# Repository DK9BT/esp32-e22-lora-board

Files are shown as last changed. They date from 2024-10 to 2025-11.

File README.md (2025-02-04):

# ESP32-E22-LoRa-board
Carrier Board for LoRa Tranceiver like E22-400M33S and ESP32 MCU

### Main Parts List:

EBYTE E22-400M33S (2W/33dBm) https://www.amazon.de/dp/B0BMP99S3D

if needed: E22->N Pigtail: https://www.amazon.de/dp/B0C8J131PD

ESP32 Board Dev Kit C V4 https://www.amazon.de/dp/B08BTS62L7/ / https://www.amazon.de/dp/B07Z83MF5W/

Adapter-Kabel zum flashen im eingebauten Zustand https://www.amazon.de/dp/B096843RY3/

BME/BMP280 3,3V https://www.amazon.de/dp/B07FS95JXT/

OLED-Display (VCC-GND-SCL-SDA): https://www.amazon.de/dp/B0C9LJ898Z/

GPS https://www.amazon.de/dp/B0D3DJ58R8/

Reichelt: https://www.reichelt.de/my/2192127

### Versions Info
**V 2.1.2  PCB** für Querformat im Gehäuse für Aussenmontage - alle Anschlüsse auf der Unterseite des Gehäuses  
oder PCB vertikale Einbau

___

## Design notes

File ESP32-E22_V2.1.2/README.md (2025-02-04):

# ESP32-E22-LoRa-board V2.1.2 - FINAL
• Carrier Board for Lora Tranceiver like E22-400M33S and ESP32 MCU  

siehe Bestückungshinweise

___
***OE3WAS - Wolfgang - 4.2.2025***

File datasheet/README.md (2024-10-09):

# Quellenverzeichnis / Links
Symbols, Footprints, 3D-Modelle

https://kicad.github.io/packages3d/  
https://support.snapmagic.com/en/articles/3758108-how-to-import-a-3d-model-in-kicad

### SMA
https://kicad.github.io/footprints/Connector_Coaxial  
https://www.snapeda.com/parts/221789-1/TE%20Connectivity/view-part/  
https://www.snapeda.com/parts/CON-SMA-EDGE-S/RF%20Solutions/view-part/  

### E22 
https://www.snapeda.com/parts/E22-400M30S/EBYTE/view-part/

### ESP32
https://grabcad.com/library/esp32-devkitc-v4-1

...

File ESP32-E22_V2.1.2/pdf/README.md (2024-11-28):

### PDF files for easier viewing

**SCH** = schematic  
**PCB** = board  
~~**_3D** = 3D files for 360° viewing~~  
**BOM** = Stückliste

~~for **3D-PDF**s you can use the **Adobe Acrobar Reader**  
or **PDF Xchange Editor** https://www.pdf-xchange.com/product/pdf-xchange-editor~~

## Bestückungsplan
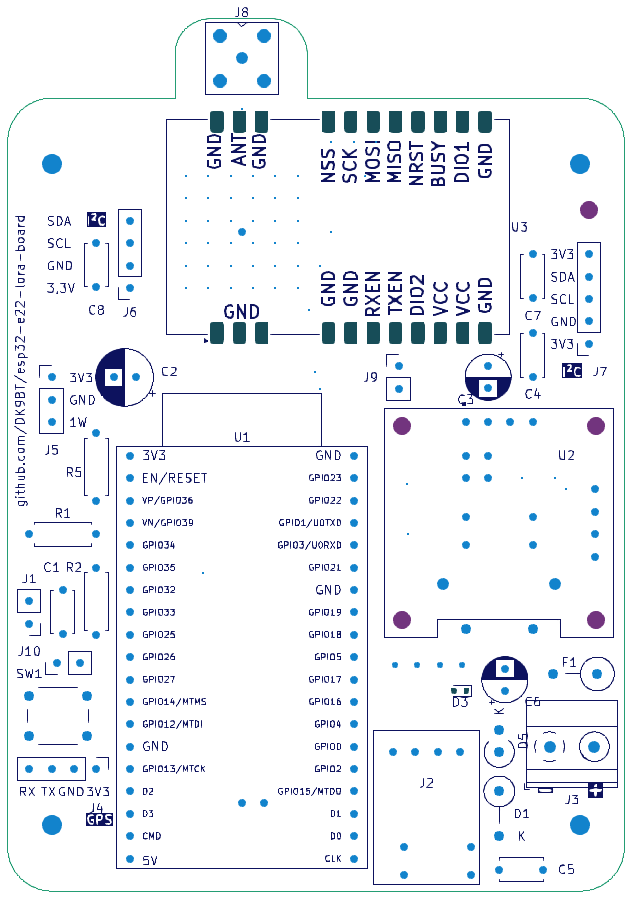
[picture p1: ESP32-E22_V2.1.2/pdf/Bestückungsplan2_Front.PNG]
  
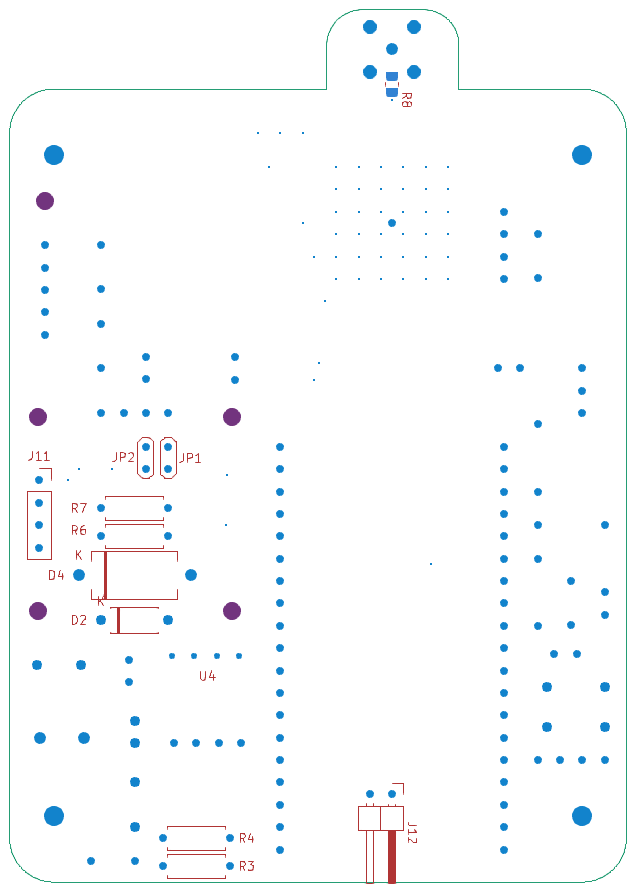
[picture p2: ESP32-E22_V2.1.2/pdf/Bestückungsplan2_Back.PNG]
  

## Querformat-Einbau für Outdoor
= alle Ausgänge an der Unterseite (OLED um 90° gedreht bestücken möglich)  
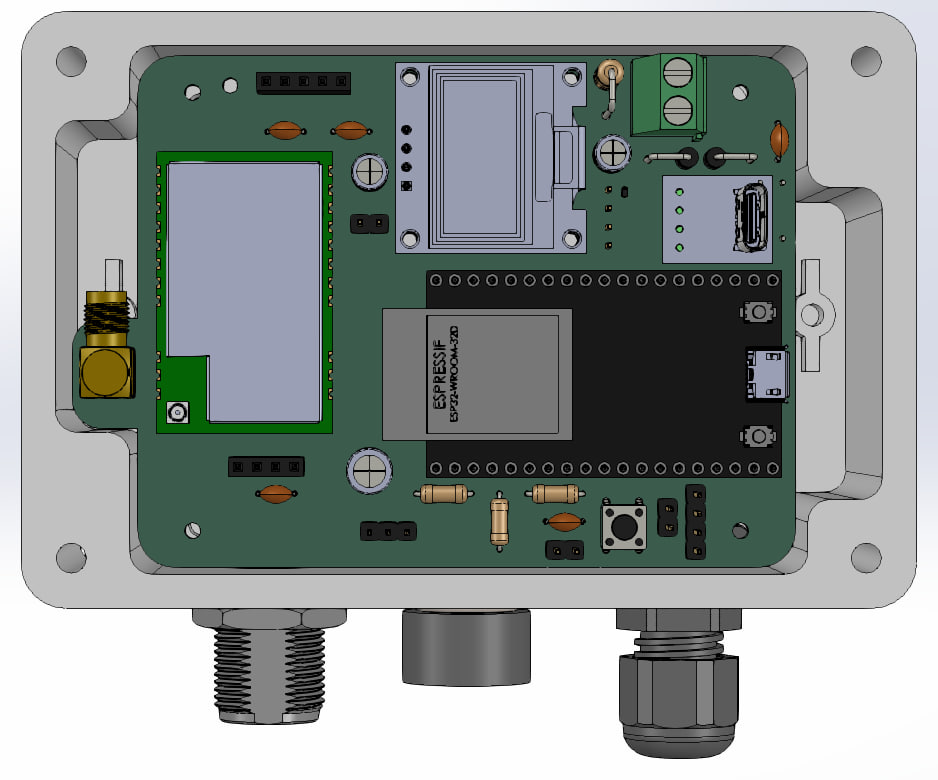
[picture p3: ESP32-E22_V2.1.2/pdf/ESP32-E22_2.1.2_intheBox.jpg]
InTheBox1
  
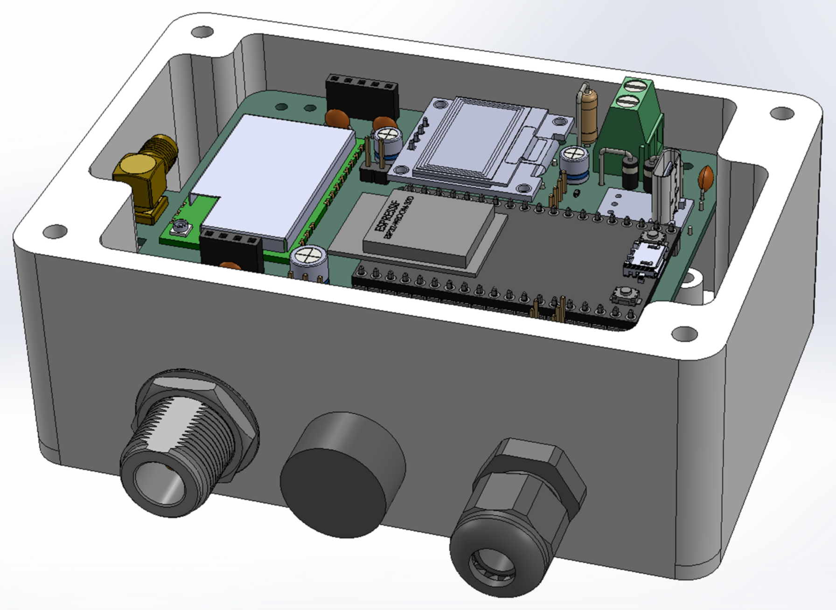
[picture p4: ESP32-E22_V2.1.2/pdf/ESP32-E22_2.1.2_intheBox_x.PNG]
InTheBox2
  
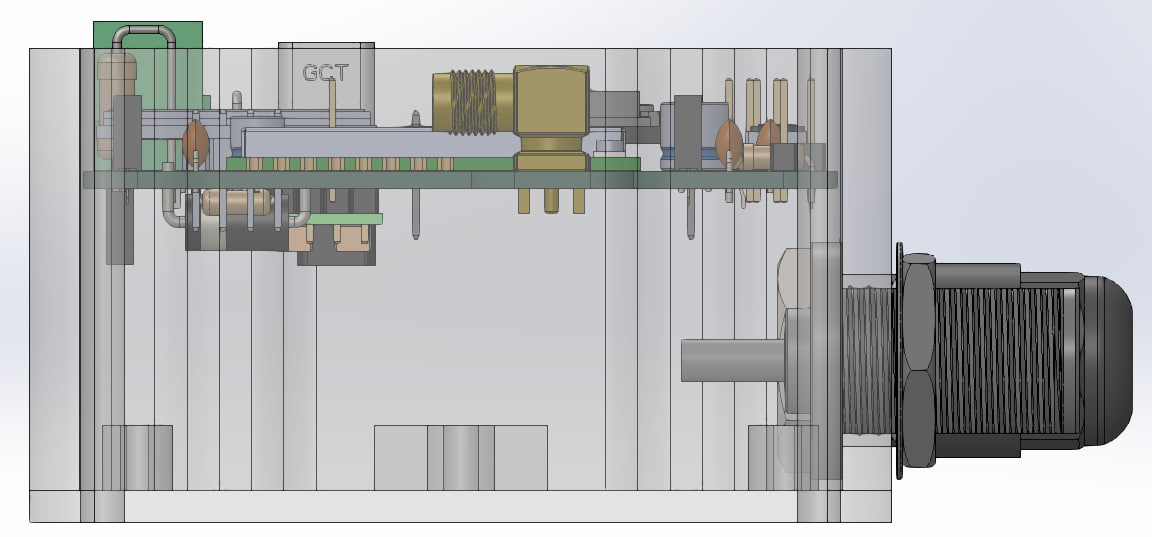
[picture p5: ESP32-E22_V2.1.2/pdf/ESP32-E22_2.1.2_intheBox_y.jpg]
InTheBox3


## Hochformat-Einbau
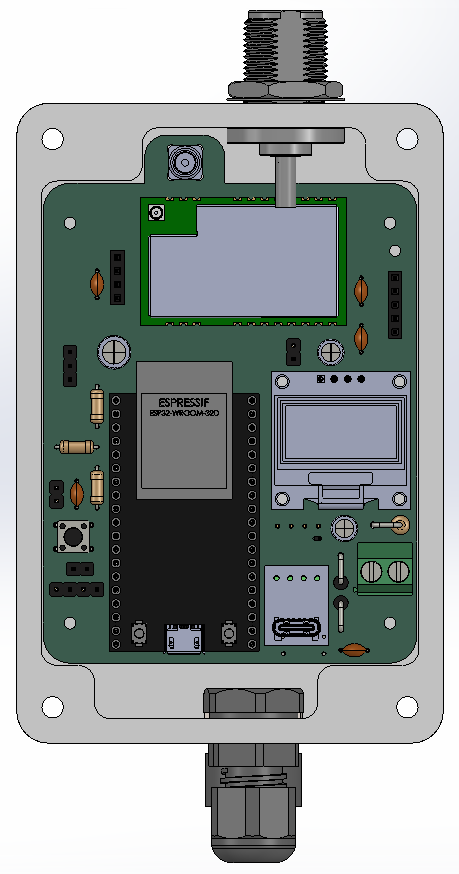
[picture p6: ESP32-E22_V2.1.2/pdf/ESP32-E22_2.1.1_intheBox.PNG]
InTheBox1
  
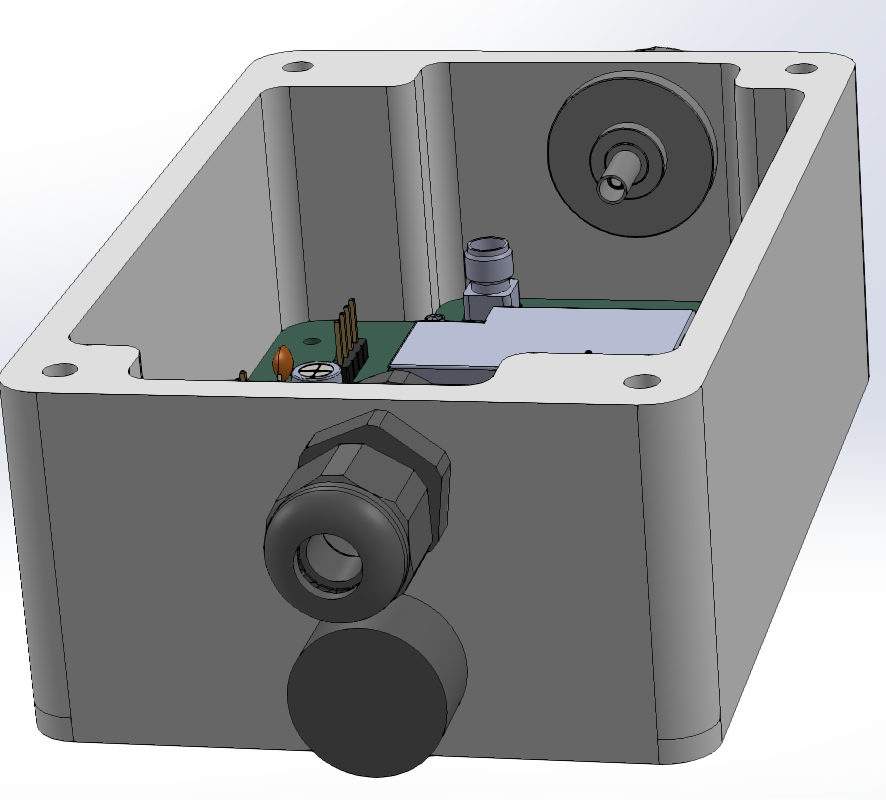
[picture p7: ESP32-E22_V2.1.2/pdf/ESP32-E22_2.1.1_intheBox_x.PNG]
InTheBox2


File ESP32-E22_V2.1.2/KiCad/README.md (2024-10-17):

### full KiCad Project

with KiCad V 8.0.5

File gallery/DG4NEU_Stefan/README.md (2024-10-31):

### DG4NEU - Stefan - Prototyp V2.1.0 Impressionen

alle Fotos mit freundlicher Genehmigung von (c) **DG4NEU Stefan**

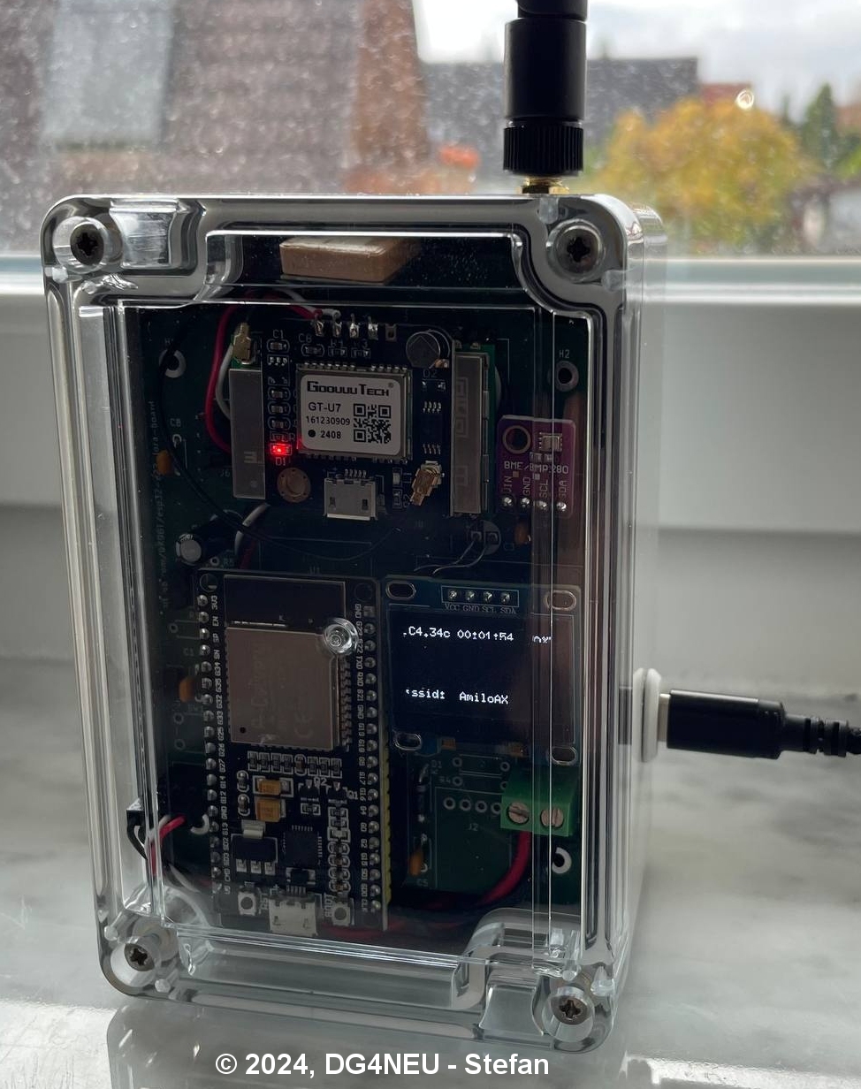
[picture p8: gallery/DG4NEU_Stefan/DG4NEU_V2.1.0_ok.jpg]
Fertiggerät


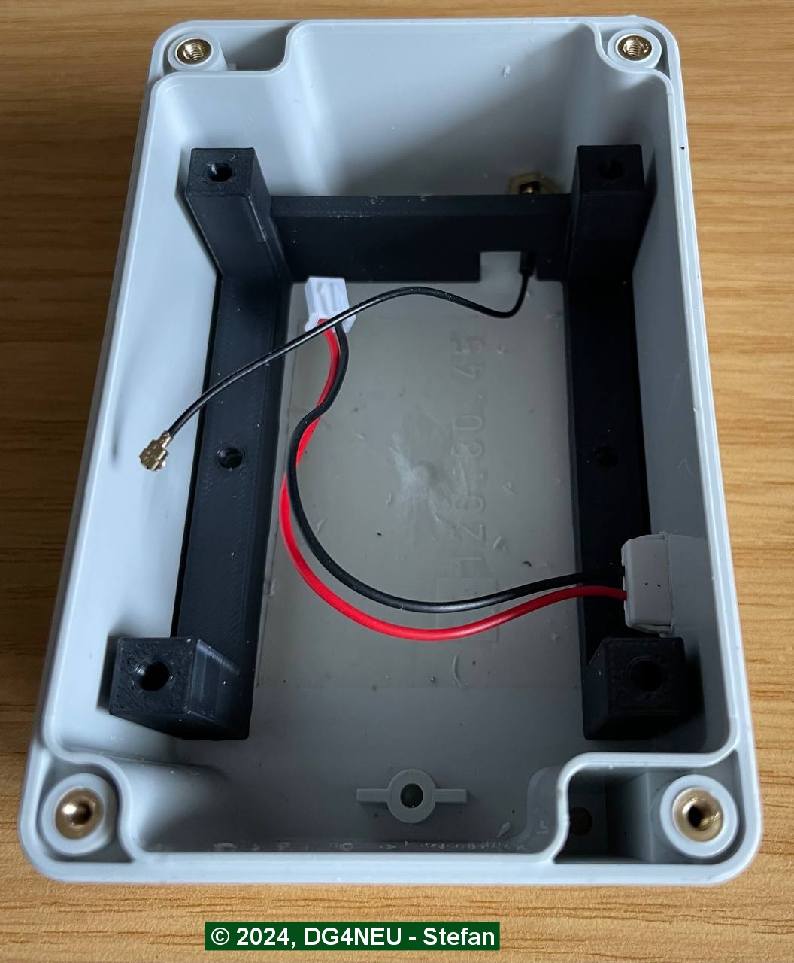
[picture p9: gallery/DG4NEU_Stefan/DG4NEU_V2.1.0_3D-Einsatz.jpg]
3D-Einsatz


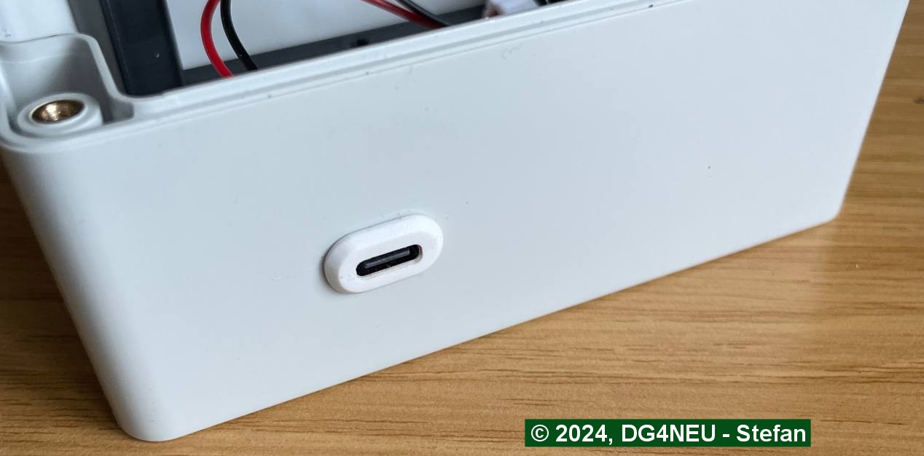
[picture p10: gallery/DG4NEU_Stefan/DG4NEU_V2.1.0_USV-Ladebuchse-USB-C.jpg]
USV-Ladebuchse-USB-C


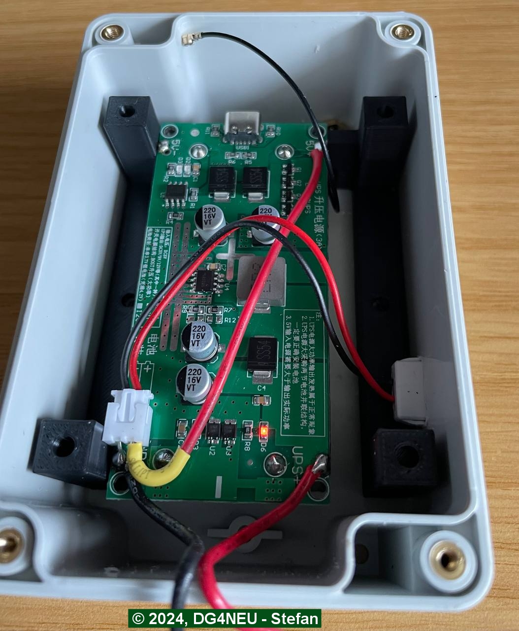
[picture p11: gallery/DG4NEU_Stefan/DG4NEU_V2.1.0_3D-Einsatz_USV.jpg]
3D-Einsatz+USV


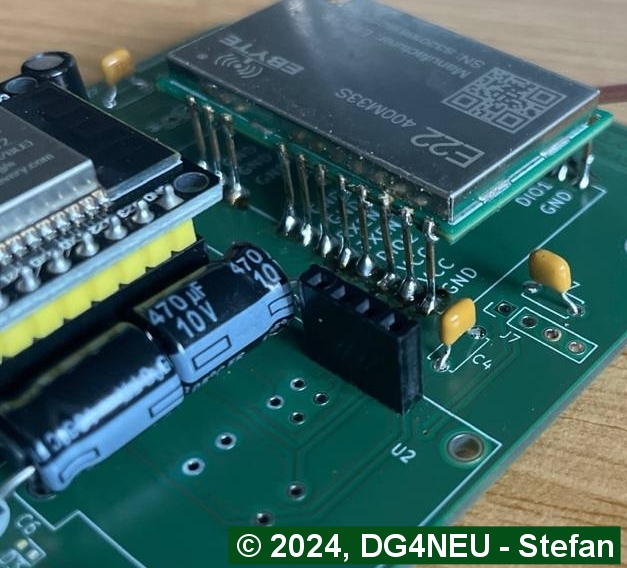
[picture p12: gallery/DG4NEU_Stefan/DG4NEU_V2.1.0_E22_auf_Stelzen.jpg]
E22_auf_Stelzen


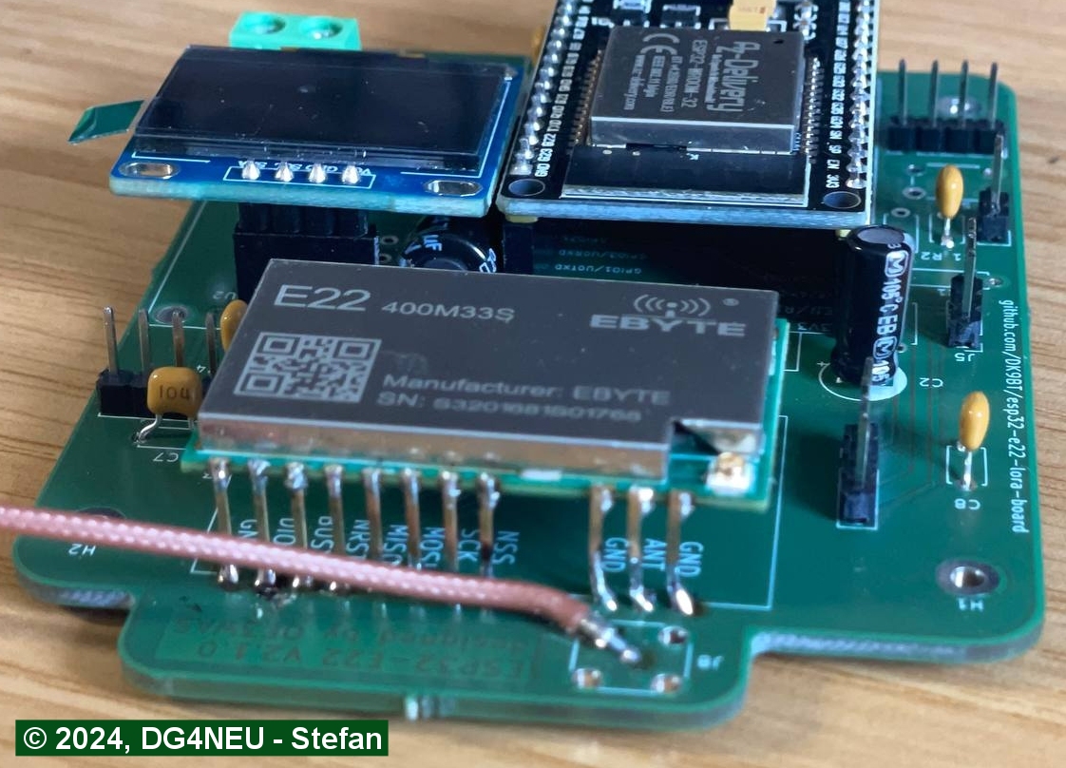
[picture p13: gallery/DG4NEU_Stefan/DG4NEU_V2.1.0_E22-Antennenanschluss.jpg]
E22+Antennenanschluss


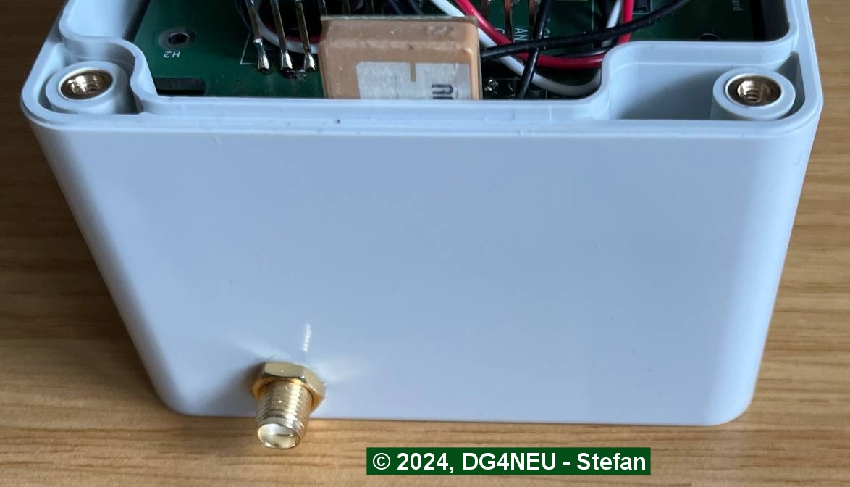
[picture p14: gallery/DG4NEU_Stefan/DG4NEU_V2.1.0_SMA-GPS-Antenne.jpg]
SMA+GPS-Antenne


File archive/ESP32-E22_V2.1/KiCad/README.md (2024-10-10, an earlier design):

### full KiCad Project

with KiCad V 8.0.5  

Beta-Version  
SCH V 2.0.11  
PCB V 2.0.6  

**Offene Fragen / Probleme, die in der nächsten Version behoben werden:**

• GND Flood

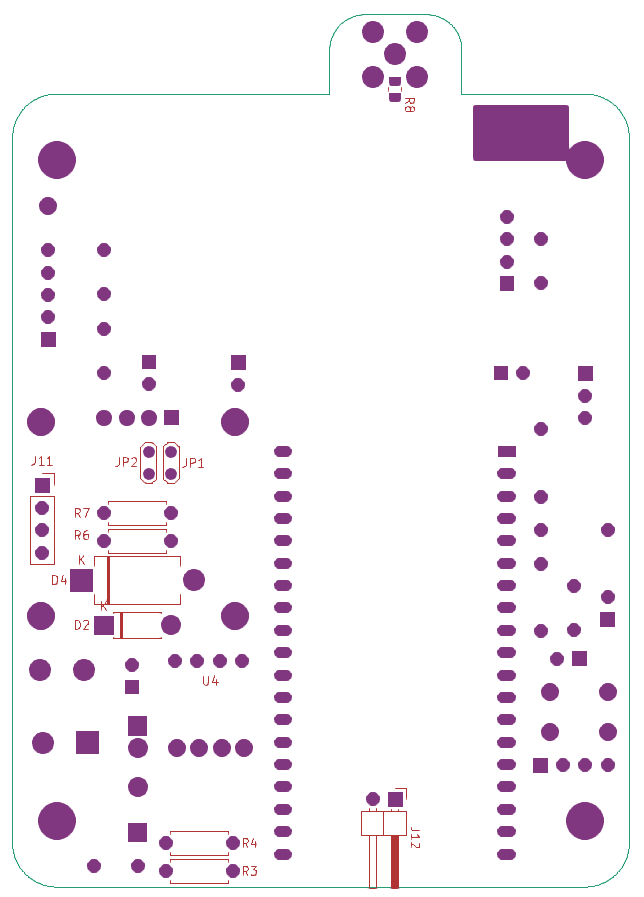
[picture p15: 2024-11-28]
ESP32-E22_V2.1.2/pdf/Bestückungsplan_Back.PNG

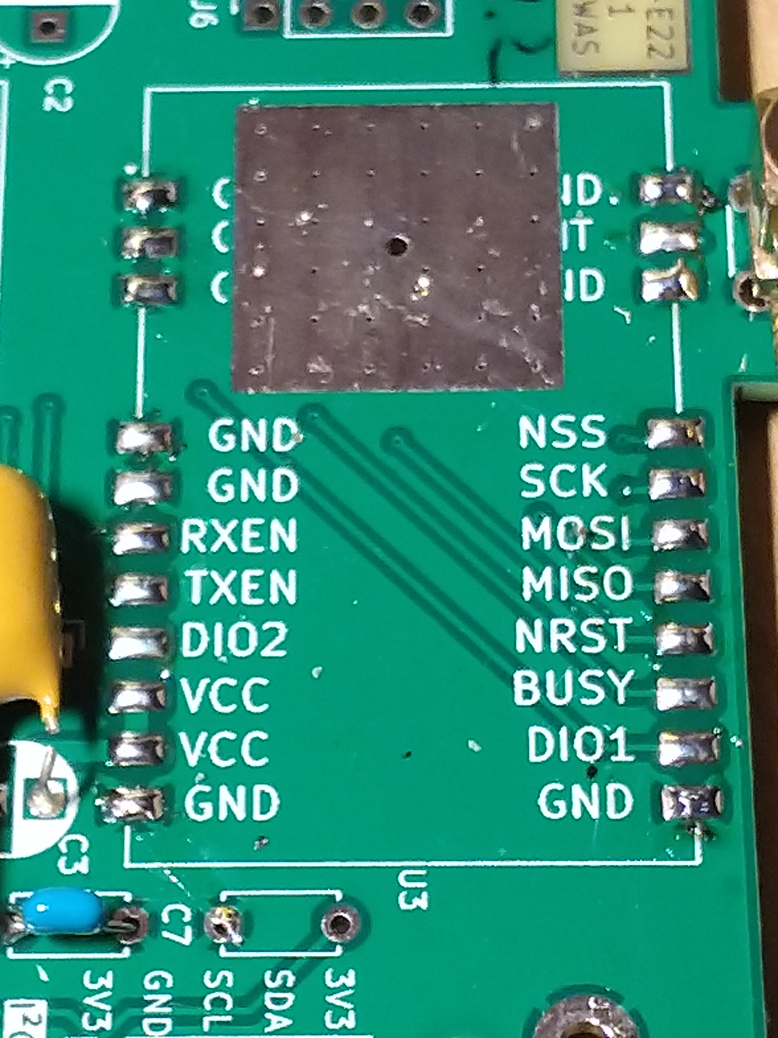
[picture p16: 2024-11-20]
ESP32-E22_V2.1.2/picass/1-1_E22_SMD.jpg

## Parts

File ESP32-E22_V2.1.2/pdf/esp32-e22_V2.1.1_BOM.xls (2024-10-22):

ESP32-E22 V 2.1.1
lfd.Nr. | Qty | Type | Value | Reference | Info
1 | 1 | ESP32-Modul | ESP32-DevKitC | U1 | …
2 | 1 | LoRa-Funkmodul | E22-400M33S | U3 | …M30S = 30dBm = 1W bzw. …M33S = 33dBm = 2W
3 | 1 | OLED-Display | DM-OLED096-636 | U2 | !!! auf das Pinning achten: VCC GND SCL SDA
4 | 1 | USB-C Adapter Board | vertical | J2 | Aliexpress https://de.aliexpress.com/item/1005007821332638.html
6 | 1 | SMA-Buchse | SMA | J8 | SMA_Amphenol_132134-14_Vertical
7 | 5 | Keramik-Kondensator | 100 nF | C1,C4,C5,C7,C8 | Capacitor_THT:C_Disc_D4.7mm_W2.5mm_P5.00mm
8 | 1 | Elektrolyt-Kondensator | 10 µF / 10V | C2 | Capacitor_THT:CP_Radial_D6.3mm_P2.50mm
9 | 2 | Elektrolyt-Kondensator | 470 µF / 10V | C3,C6 | Capacitor_THT:CP_Radial_D5.0mm_P2.50mm
10 | 2 | Schottky-Diode | 1N5817 | D1,D2 | Diode_THT:D_DO-41_SOD81_P7.62mm_Horizontal
11 | 1 | ESD-Schutz-Diode | LESD5D5.0CT1G | D3 | Diode_SMD:D_SOD-523
12 |  | ESD-Schutz-Diode | 1N5908 | D3 | alternativ auf Rückseite auflöten
13 | 1 | Sicherung | 5A | F1 | https://www.conrad.at/de/p/littelfuse-0874002-mxep-0874002-mxep-sicherung-inhalt-1-st-bulk-2943788.html
14 | 2 | Widerstand | 5k1 | R1,R2 | Resistor_THT:R_Axial_DIN0207_L6.3mm_D2.5mm_P7.62mm_Horizontal
15 | 2 | Widerstand | *) | R3,R4 | *) Werte für Spannungsteiler je nach Bedarf
16 | 1 | Widerstand | 4k7 | R5 | Resistor_THT:R_Axial_DIN0207_L6.3mm_D2.5mm_P7.62mm_Horizontal
17 | 2 | Widerstand | 10k | R6,R7 | Resistor_THT:R_Axial_DIN0207_L6.3mm_D2.5mm_P7.62mm_Horizontal
18 | 1 | Jumper | 0R | R8 | Resistor_SMD:R_0805_2012Metric
19 | 1 | Taster |  | SW1 | Button_Switch_THT:SW_PUSH_6mm
20 | 1 | Schraubklemme | 2-pol | J1 | z.B. Phoenix_MKDS-1,5-2-5.08_1x02_P5.08mm_Horizontal
21 | 2 | St-/Bu-Leiste | Conn_01x02._Socket | J3,J9 | PinHeader_1x02_P2.54mm_Vertical
22 | 1 | St-/Bu-Leiste | Conn_01x03_Socket | J5 | PinHeader_1x03_P2.54mm_Vertical
23 | 3 | St-/Bu-Leiste | Conn_01x04_Socket | J4,J6,J7 | PinHeader_1x04_P2.54mm_Vertical
24 | 1 | PCB | ESP32-E22 V2.1.0
25 | 1 | Gehäuse | 120x80x60 | 6U07120806017 | Reichelt #340515 od. transparenter Deckel #340524 (6U07120806437)
26 | 4 | Schraube | M2x6 (M2x8) | PCB | Befestigung im Gehäuse, siehe "Modellbauschrauben"
27 | 2 | Schraube | M2x15 (?) | OLED | Befestigung auf PCB, siehe "Modellbauschrauben"
28 | 2 | Distanzhülse | aus MS-Rohr Ø3x50 | OLED | Befestigung auf PCB, siehe "Modellbauschrauben"
29 | 4 | Einpressmutter | M2x4xØ3,5 |  | versch. Lieferanten
30 | 1 | PG-Verschraubung | PG7 |  | https://www.reichelt.at/at/de/shop/produkt/kabelverschraubung_pg7_grau_10er-pack-281164
31 |  | PG-Verschraubung | PG7 m. Zugentlastung |  | https://www.reichelt.at/at/de/shop/produkt/kabelverschraubung_mit_zugentlastung_pg7_gr-302864
32 | 1 | Druckausgleich | M12 |  | https://www.reichelt.at/at/de/shop/produkt/druckausgleichselement_m12_schwarz_2_stueck-371154
33 | 1 | Programmierkabel | USB-A <> USB-Mikro |  | https://www.reichelt.at/at/de/shop/produkt/dual_easy_usb_2_0_kabel_a_st_auf_micro_b_st_gew_0_2_m-287766

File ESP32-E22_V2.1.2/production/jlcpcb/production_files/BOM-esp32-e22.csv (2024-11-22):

Comment | Designator | Footprint | LCSC | Quantity
Conn_01x03_Socket | J5 | PinHeader_1x03_P2.54mm_Vertical |  | 1
5k1 | R1 | R_Axial_DIN0207_L6.3mm_D2.5mm_P7.62mm_Horizontal |  | 1
470µF | C6 | CP_Radial_D5.0mm_P2.50mm |  | 1
Screw_Terminal_01x02 | J3 | TerminalBlock_Phoenix_MKDS-1,5-2-5.08_1x02_P5.08mm_Horizontal |  | 1
5k1 | R2 | R_Axial_DIN0207_L6.3mm_D2.5mm_P7.62mm_Horizontal |  | 1
1N4007 | D5 | D_DO-41_SOD81_P2.54mm_Vertical_KathodeUp |  | 1
10µF | C2 | CP_Radial_D6.3mm_P2.50mm |  | 1
DM-OLED096-636 | U2 | DM-OLED096-636 |  | 1
4k7 | R5 | R_Axial_DIN0207_L6.3mm_D2.5mm_P7.62mm_Horizontal |  | 1
~ | J2 | USB-C_vert |  | 1
Conn_01x02_Socket | J1 | PinHeader_1x02_P2.54mm_Vertical |  | 1
Conn_01x04_Socket | J6 | PinSocket_1x04_P2.54mm_Vertical |  | 1
1N5817 | D1 | D_DO-41_SOD81_P5.08mm_Vertical_KathodeUp |  | 1
100nF | C4 | C_Disc_D4.7mm_W2.5mm_P5.00mm |  | 1
Conn_01x05_Socket | J7 | PinSocket_1x05_P2.54mm_Vertical |  | 1
100nF | C5 | C_Disc_D4.7mm_W2.5mm_P5.00mm |  | 1
SMA | J8 | SMA_Amphenol_901-143_Horizontal |  | 1
470µF | C3 | CP_Radial_D5.0mm_P2.50mm |  | 1
E22-400M33S | U3 | E22-400M33S |  | 1
Conn_01x04_Socket | J4 | PinHeader_1x04_P2.54mm_Vertical |  | 1
ESP32-DevKitC V4 | U1 | ESP32-DevKitC |  | 1
100nF | C7 | C_Disc_D4.7mm_W2.5mm_P5.00mm |  | 1
100nF | C1 | C_Disc_D4.7mm_W2.5mm_P5.00mm |  | 1
2A | F1 | R_Axial_DIN0411_L9.9mm_D3.6mm_P5.08mm_Vertical |  | 1
100nF | C8 | C_Disc_D4.7mm_W2.5mm_P5.00mm |  | 1
Conn_01x02_Socket | J10 | PinHeader_1x02_P2.54mm_Vertical |  | 1
SW_Push | SW1 | SW_PUSH_6mm |  | 1
LESD5D5.0CT1G | D3 | D_SOD-523 |  | 1
Conn_01x02_Socket | J9 | PinHeader_1x02_P2.54mm_Vertical |  | 1
1N5908 | D4 | D_DO-201_P12.70mm_Horizontal |  | 1
HW-613 | U4 | HW-613 |  | 1
Jumper_2_Small_Bridged | JP1 | TestPoint_2Pads_Pitch2.54mm_Drill0.8mm |  | 1
5k1 | R4 | R_Axial_DIN0207_L6.3mm_D2.5mm_P7.62mm_Horizontal |  | 1
0R | R8 | R_0805_2012Metric |  | 1
Conn_01x02_Socket | J12 | PinHeader_1x02_P2.54mm_Horizontal |  | 1
10k | R7 | R_Axial_DIN0207_L6.3mm_D2.5mm_P7.62mm_Horizontal |  | 1
1N5817 | D2 | D_DO-41_SOD81_P7.62mm_Horizontal |  | 1
Jumper_2_Small_Bridged | JP2 | TestPoint_2Pads_Pitch2.54mm_Drill0.8mm |  | 1
Conn_01x04_Socket | J11 | PinSocket_1x04_P2.54mm_Vertical |  | 1
10k | R6 | R_Axial_DIN0207_L6.3mm_D2.5mm_P7.62mm_Horizontal |  | 1
5k1 | R3 | R_Axial_DIN0207_L6.3mm_D2.5mm_P7.62mm_Horizontal |  | 1

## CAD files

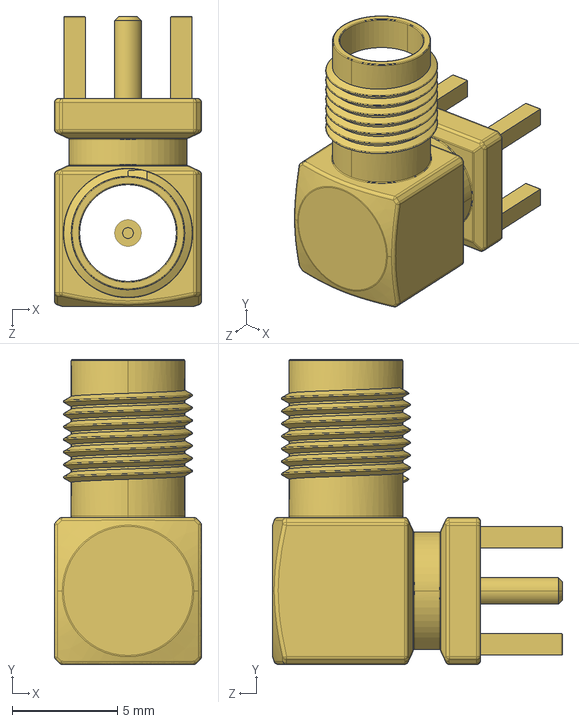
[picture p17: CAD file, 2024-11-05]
ESP32-E22_V2.1.2/KiCad/3D_model/SMA-angled.STEP
7.00 x 14.5 x 13.8 mm

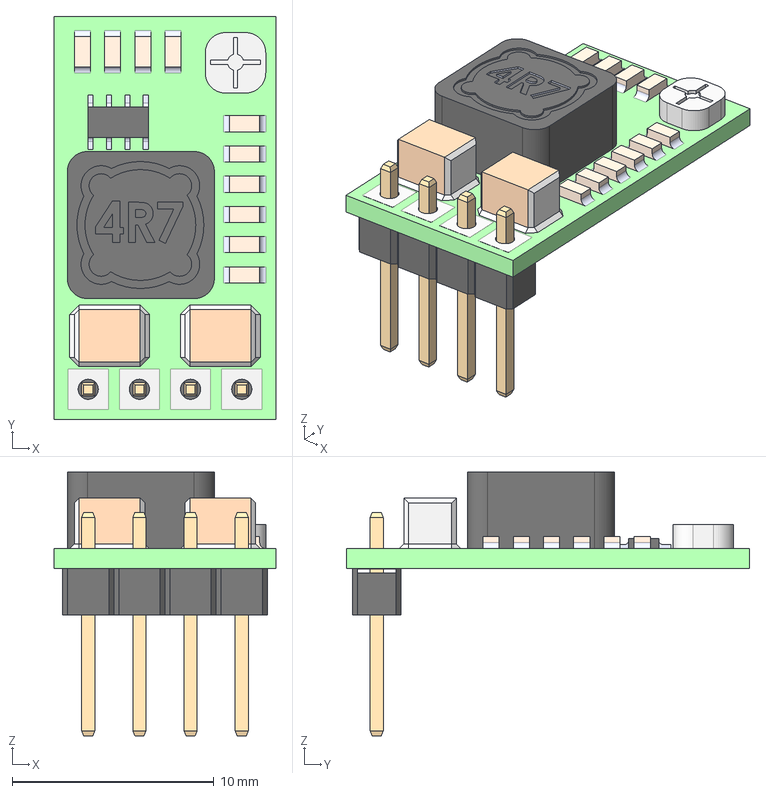
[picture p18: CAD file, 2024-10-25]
ESP32-E22_V2.1.2/KiCad/3D_model/HW-613.step
11.0 x 20.0 x 13.1 mm

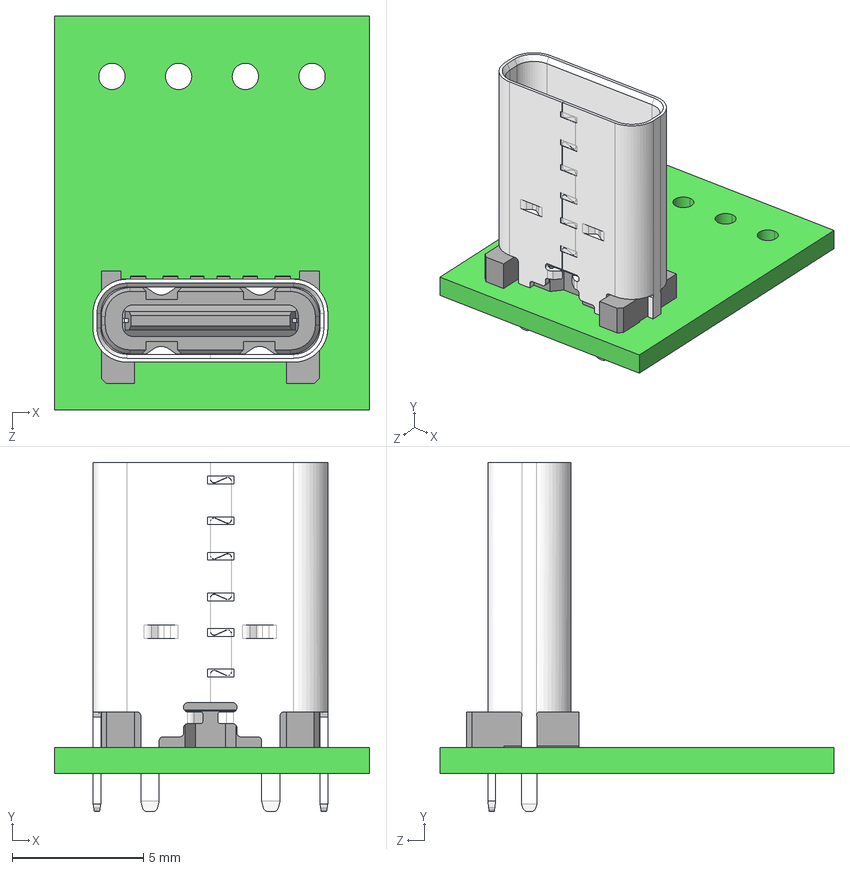
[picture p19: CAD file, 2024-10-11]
ESP32-E22_V2.1.2/KiCad/3D_model/USB-C_vert_breakout.STEP
12.0 x 13.3 x 15.0 mm
USB-C connector
USB4175-GF-0230-C_PART2
USB4175-GF-0230-C_PART1

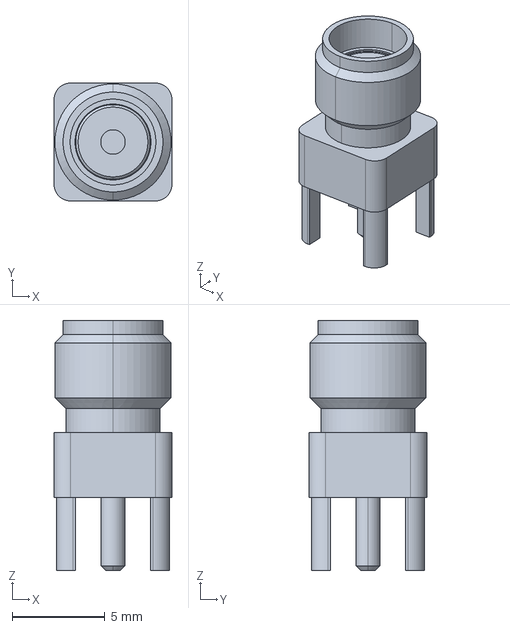
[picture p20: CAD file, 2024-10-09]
ESP32-E22_V2.1.2/KiCad/3D_model/SMA_221789-1.step
6.35 x 6.35 x 13.5 mm

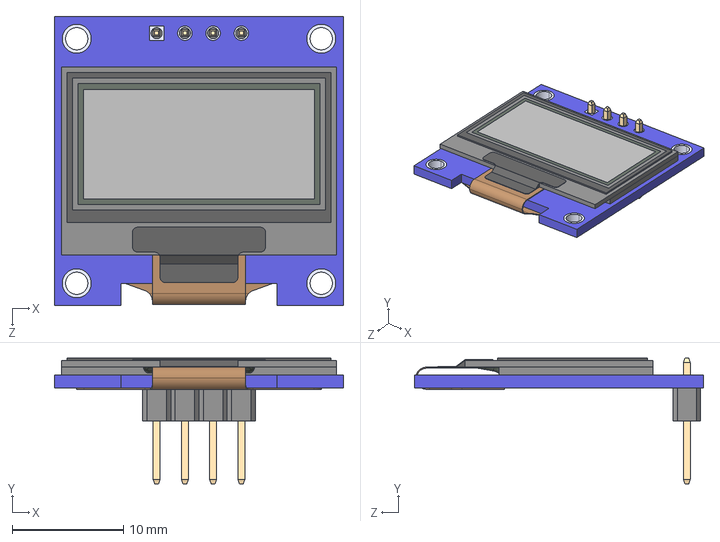
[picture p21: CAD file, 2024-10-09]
ESP32-E22_V2.1.2/KiCad/3D_model/DM-OLED096-636.step
26.0 x 11.3 x 26.0 mm
DM-OLED096-636_Module
DM-OLED096-636_Panel

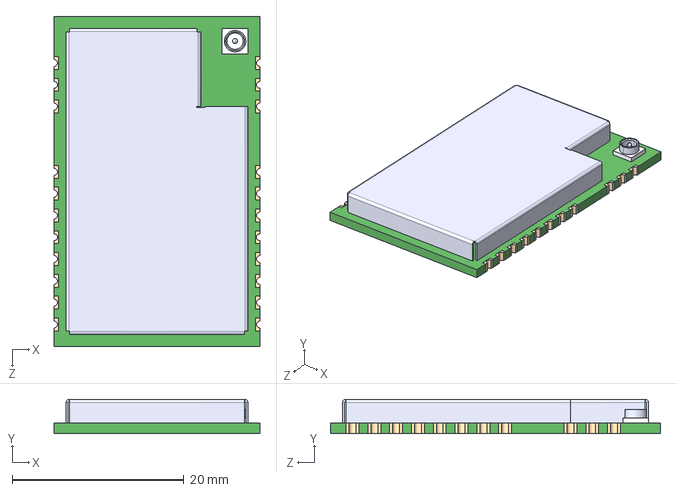
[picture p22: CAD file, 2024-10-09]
ESP32-E22_V2.1.2/KiCad/3D_model/E22-400M30S-3D.STEP
24.0 x 3.97 x 38.5 mm

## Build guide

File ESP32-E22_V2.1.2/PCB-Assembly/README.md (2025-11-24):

# Bestückungshinweise PCB V2.1.2

Bestückungsreihenfolge, Varianten und Inbetriebnahme des PCB V2.1.2  

Bilder zum fertigen Gerät sind hier zu finden:  
https://github.com/DK9BT/esp32-e22-lora-board/tree/main/ESP32-E22_V2.1.2/pdf  
Fertig bestückte Varianten sind hier zu finden:  
https://github.com/DK9BT/esp32-e22-lora-board/tree/main/gallery

## 1) Minimalbestückung
* Die folgenden BT sind das absolute Minimum für die grundsätzliche Funktion.
* Über die USB-mikro Buchse am ESP32 kann auch das E22-Modul versorgt werden, wenn ein passendes USB-Netzgerät verwendet wird, welches mind. 2A bereitstellen kann.

### 1.1 Key-Components
* **PCB V2.1.2**
* **U1 = ESP32-DevKitC-V4**
* **U2 = OLED 0,96"**
* **U3 = E22-400M30S** (30dBm) od. **E22-400M33S** (33dBm) od. **E22-900M30S** (30dBm!)

### 1.2 Einbau-Varianten für U3 = E22-fffM3xS
> [!NOTE]
> **Dieses BT sollte als Erstes bestückt werden, um gut an die Lötstellen zu kommen.**

**a)** Das **E22-Modul** ist für **SMD-Direktlötung** vorgesehen. Der NT ist, dass es bei einem Defekt schwieriger abzulöten ist.  
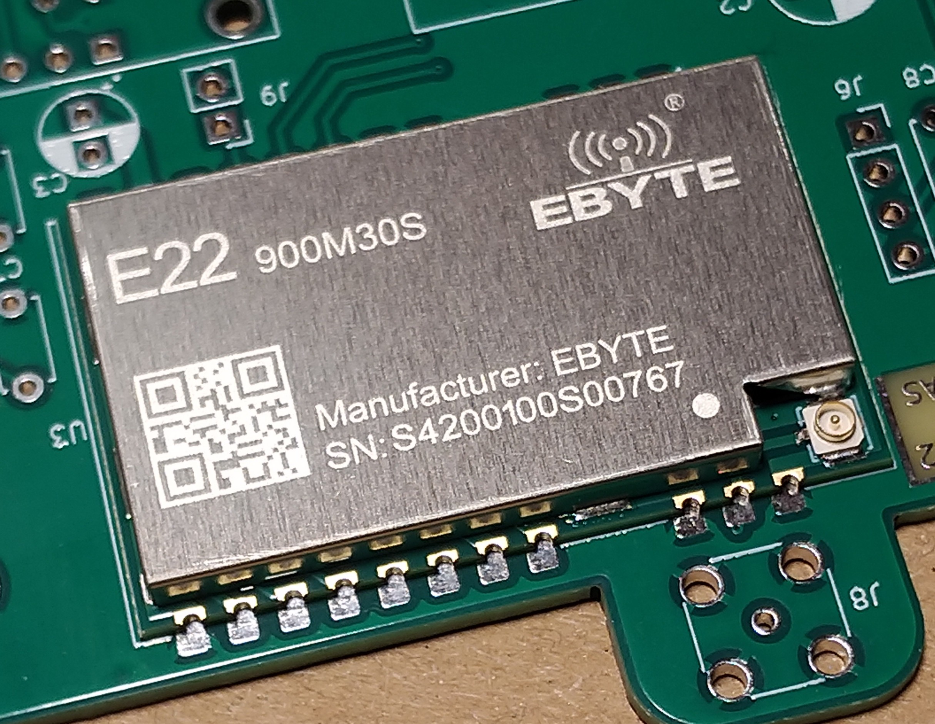
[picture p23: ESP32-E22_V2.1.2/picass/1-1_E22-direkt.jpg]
E22-direkt
  

**b)** **E22-Modul auf Sockel (Variante für PCB V2.1.2)**  
Obwohl der Pin-Abstand des E22-Moduls 2,50mm beträgt, ist es trotzdem möglich, Stifte und Buchsen im RM 2,54 zu verwenden.  
Bei dieser Art der Bestückung wird sozusagen ein Stecksockel aus einfachen, günstigen und handelsüblichen Teilen hergestellt.  
In einer späteren Version wird es eine Sockeladapterplatine geben und eine modifizierte PCB.

<ins>**Schritt 1:**</ins> Durchkontaktierte Lochrasterplatte 35x27mm (13x10 Löcher) mit **2x 8pol** + **2x 3pol Pfosten-Buchsen** bestücken und mit Stiftleisten stabilisieren.  
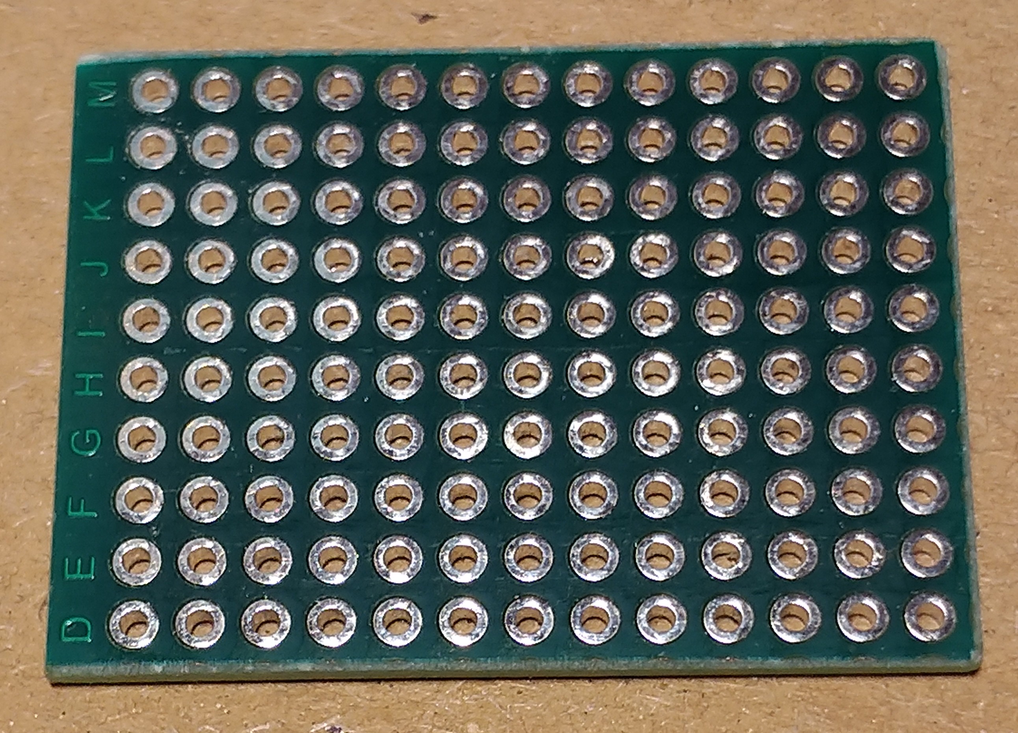
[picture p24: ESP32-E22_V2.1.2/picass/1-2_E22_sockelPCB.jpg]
E22_sockelPCB
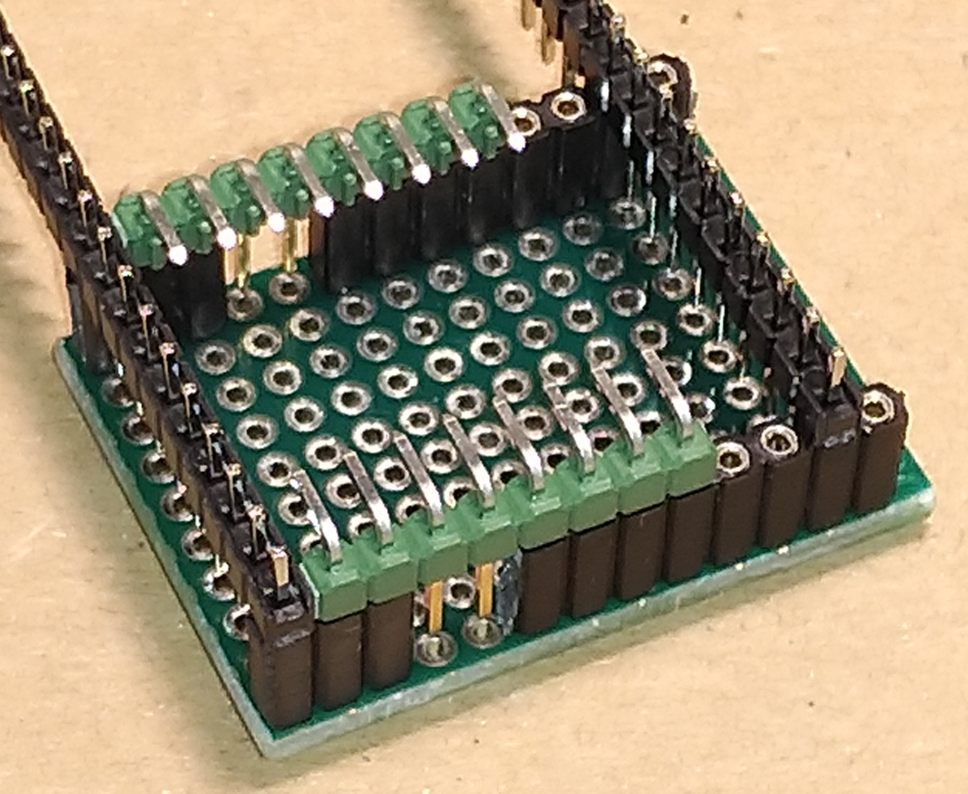
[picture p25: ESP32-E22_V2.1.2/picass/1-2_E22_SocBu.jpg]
E22_SocBu
  

<ins>**Schritt 2:**</ins> verlöten und Lötstellen plan feilen, damit das E22-Modul plan aufliegen kann und gut verlötbar ist.  
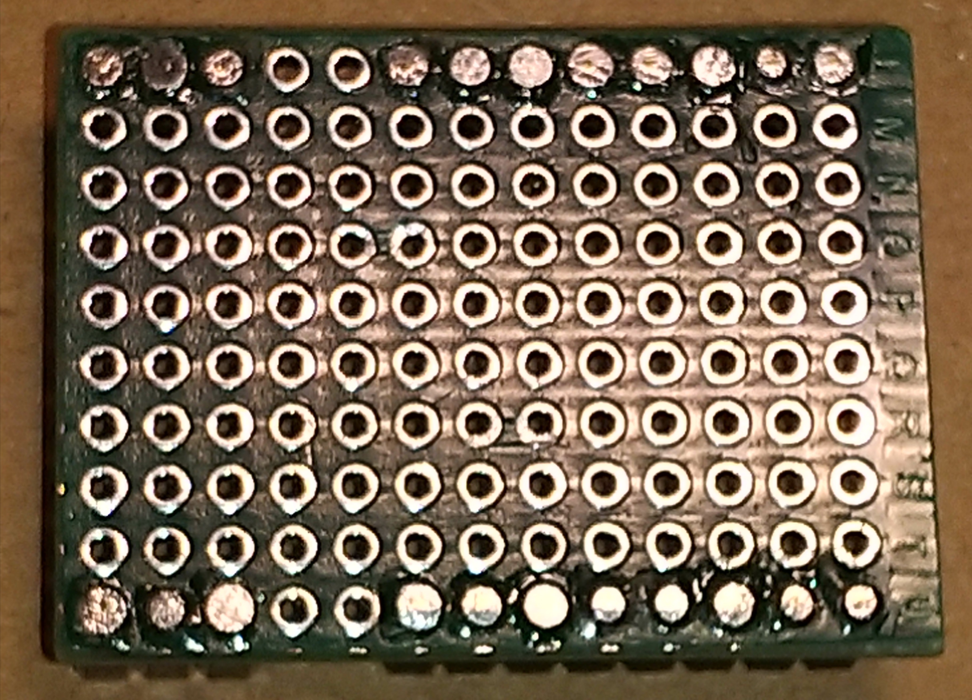
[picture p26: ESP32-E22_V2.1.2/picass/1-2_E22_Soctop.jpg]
E22_Soctop
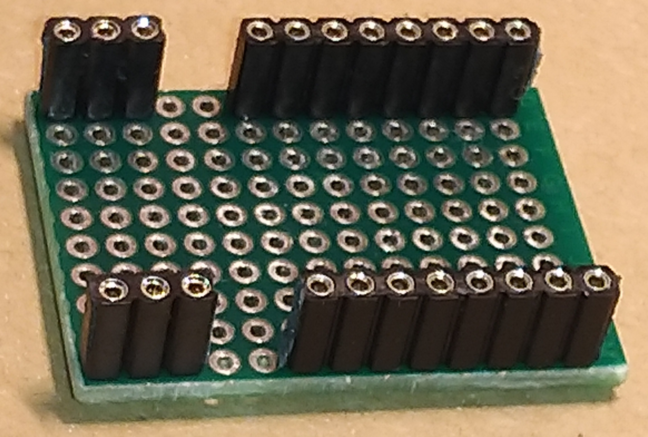
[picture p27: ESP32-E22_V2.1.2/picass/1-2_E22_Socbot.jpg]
E22_Socbot
  

<ins>**Schritt 3:**</ins> **2x 8pol** + **2x 3pol Pfostenstecker gewinkelt** zur Stabilisierung in die Pfosten-Buchsen stecken und das kürzere Ende noch weiter kürzen.  
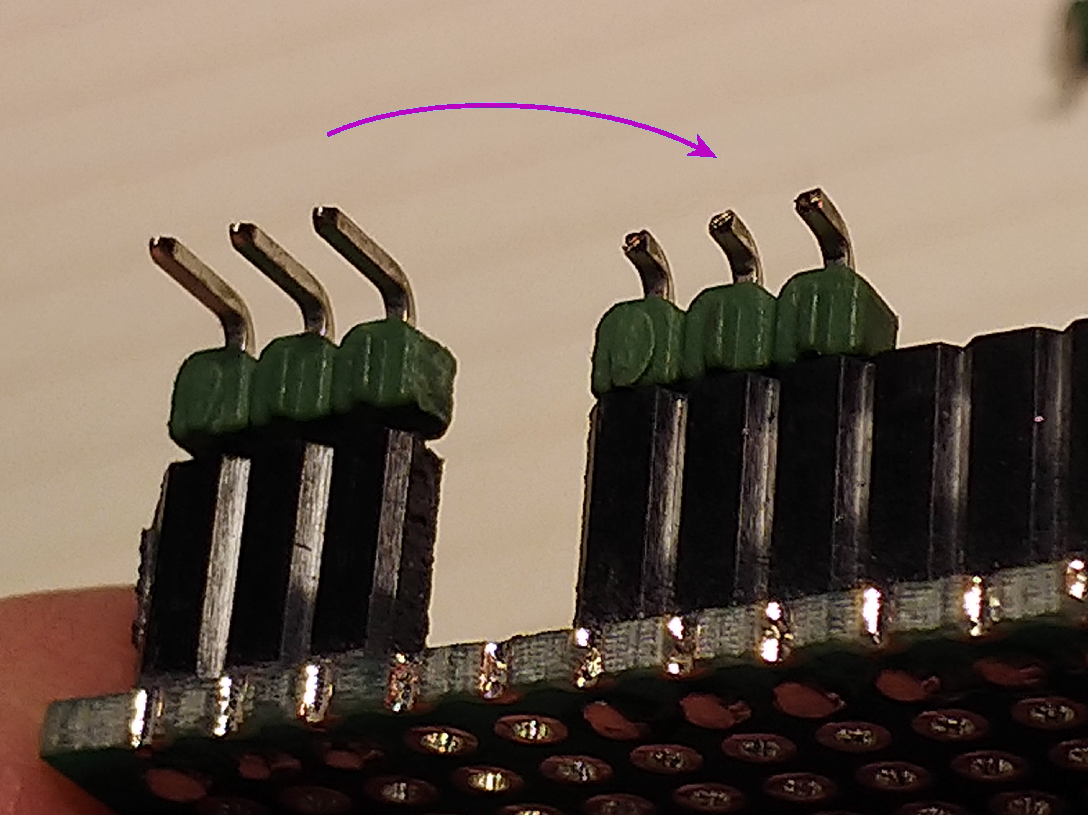
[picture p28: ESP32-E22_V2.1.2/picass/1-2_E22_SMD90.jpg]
E22_SMD90
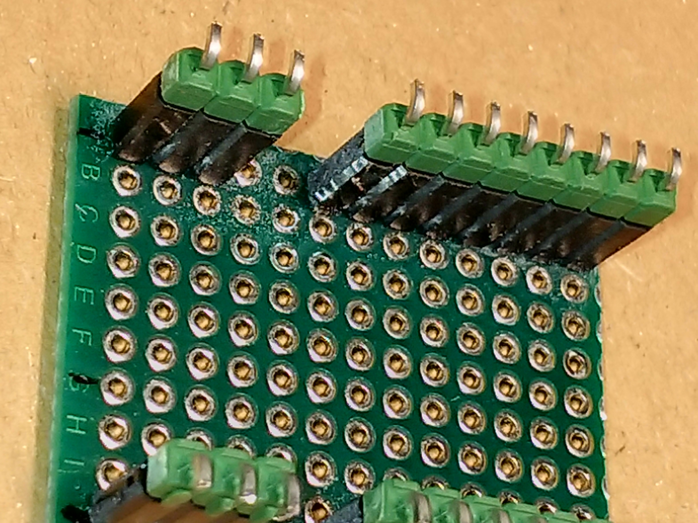
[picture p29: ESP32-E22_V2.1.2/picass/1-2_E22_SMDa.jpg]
E22_SMDa
  

<ins>**Schritt 4:**</ins> auf die PCB wie ein SMD-BT auflöten.  
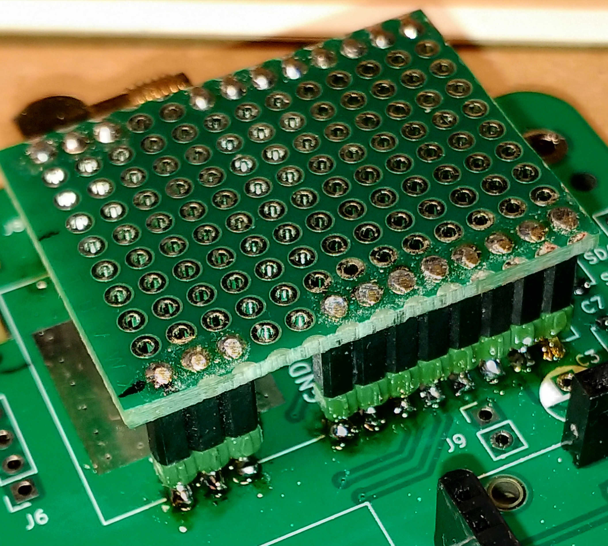
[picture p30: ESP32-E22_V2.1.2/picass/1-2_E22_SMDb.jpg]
E22_SMDb
  

<ins>**Schritt 5:**</ins> **C3** (220..470µF, liegender Einbau) & **C4** (100nF) bestücken.

### 1.3 Einbau-Varianten für U1 = ESP32-DevKitC V4
Die **V4** ist die derzeit neueste Version. Es können aber grundsätzlich auch die **V1**- od. **V4**-Module verwendet werden.  
> [!NOTE]
> Die Unterschiede werden an anderer Stelle detailliert dargestellt. [!TODO]

* **a)** Normalerweise verwendet man eine Pfosten-Steckverbindung, wobei die Buchsenleisten in das PCB eingelötet sind und die Pfostenstecker sich am ESP32-Modul befinden, **je 2x 19-pol**:  
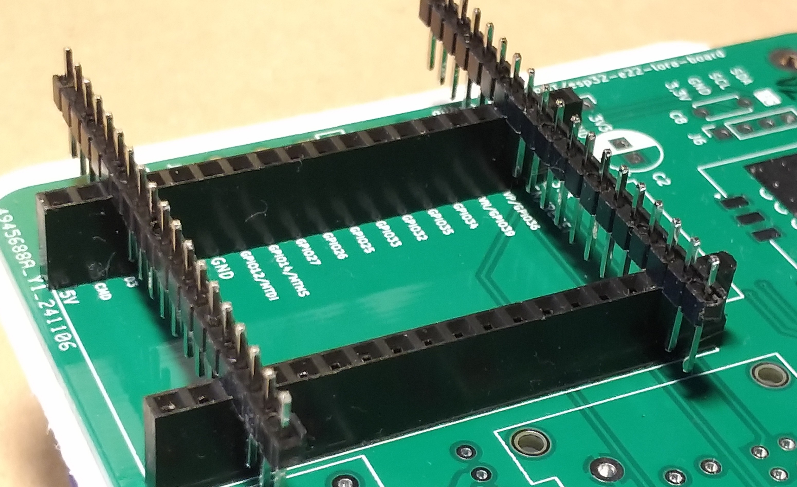
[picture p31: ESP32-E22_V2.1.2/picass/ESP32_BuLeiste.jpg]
ESP32_BuLeiste
  

* **b)** Es können aber auch IC-Sockelstifte & Sockelbuchsen verwendet werden. Dies hat den Vorteil, dass das ESP32-Modul problemlos auf ein Steckbrett eingesteckt werden kann.  
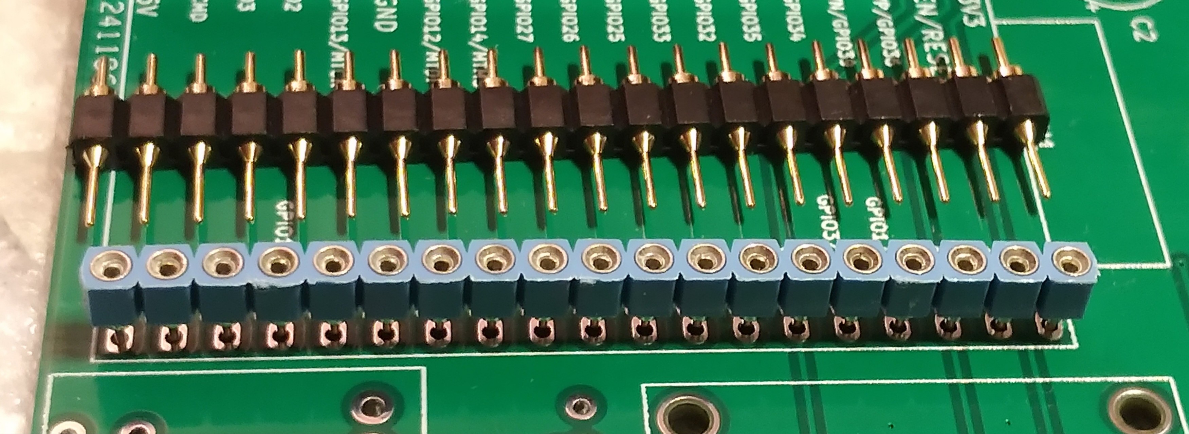
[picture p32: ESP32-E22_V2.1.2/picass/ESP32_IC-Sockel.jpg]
ESP32_IC-Sockel
  

### 1.4 OLED 0,96"
Für das OLED sind 2 Positionen 0°=Hochformat & 90°=Querformat (J11) vorgesehen, die mit **2x 4-pol Bu-Streifen** bestückt werden.  
Die OLED gibt es in grundsätzlich 2 verschiedenen Pin-Anordnungen. Die angegebene (**VCC-GND-SCL-SDA**) ist bereits auf der PCB verdrahtet. Falls man VCC <> GND umdrehen möchte, dann sind auf der Rückseiten 2 Leiterbahnen zu unterbrechen und 2 Drahtbrücken herzustellen (JP1 & JP2).  
Bei manchen OLEDs (rechts im Bild) kann man noch die **I²C**-Adresse von **`0x78`** auf **`0x7A`** ändern.  
Mit einem I²C-Scanner werden **`0x78` >> `0x3C`** und **`0x7A` >> `0x3D`** erkannt (7-Bit Format).  
Zusätzlich können auf manchen Modulen direkt die **VCC<>GND** durch die **J1/J2/J3/J4** im Foto rechts vertauscht werden.  
Das linke OLED verwendet einen **SH1106**-Driver (132x64 pixel), das rechte einen **SSD1306**-Driver (128x64 pixel).  
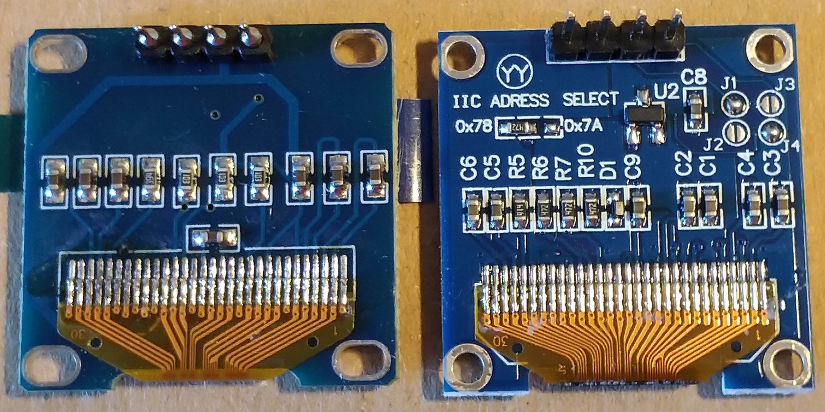
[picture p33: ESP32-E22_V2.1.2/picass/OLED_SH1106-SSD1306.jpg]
OLED_SH1106-SSD1306
  
Das OLED-Board kann über eine Abstandshülse Ø4x11 mit M2 Gewindebohrung beidseits mit M2x5 Schrauben auf dem PCB mechanisch fixiert werden.  
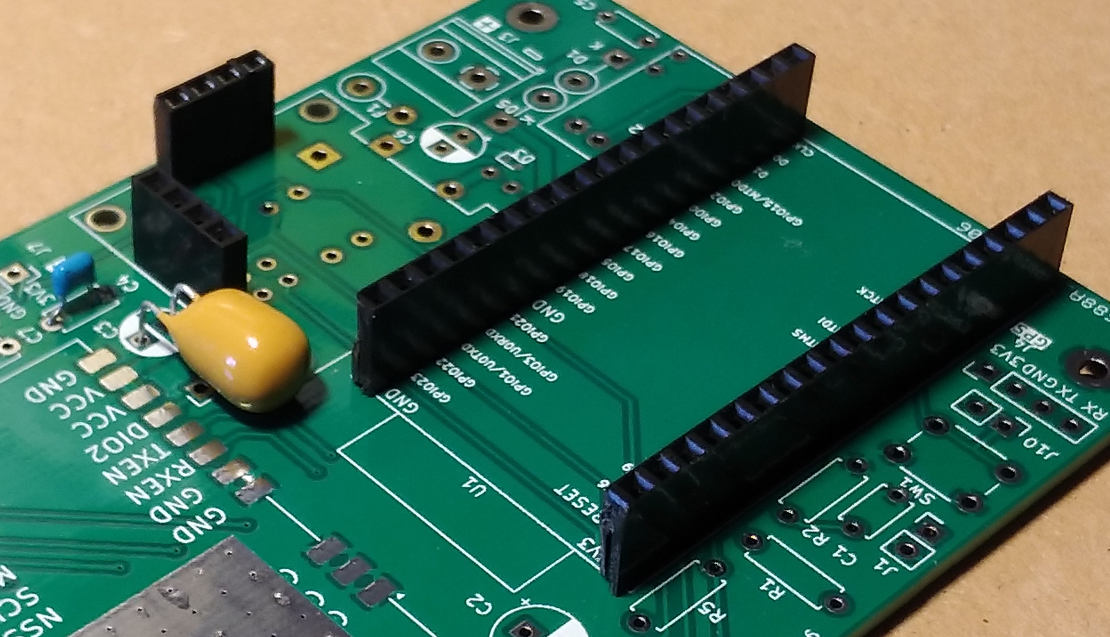
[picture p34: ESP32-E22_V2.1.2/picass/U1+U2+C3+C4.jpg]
U1+U2+C3+C4
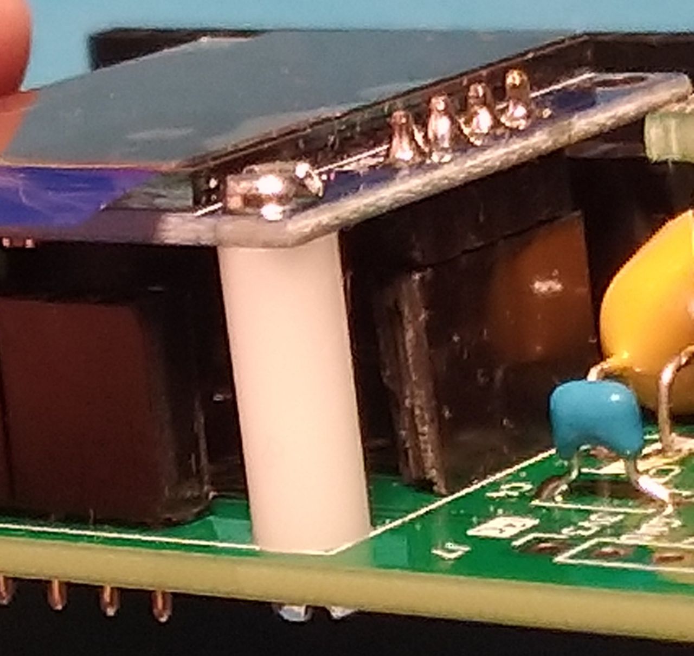
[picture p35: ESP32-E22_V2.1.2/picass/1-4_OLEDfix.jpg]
OLEDfix


### 1.5 User Button
Ein Taster **SW1** ist an **GPIO12** angeschlossen. Parallel dazu kann über **J10** ein Taster extern, zB. am Gehäuse, verbunden werden.  
Für **MeshCom** muss er erstmalig mit **`--button on`** aktiviert werden.  
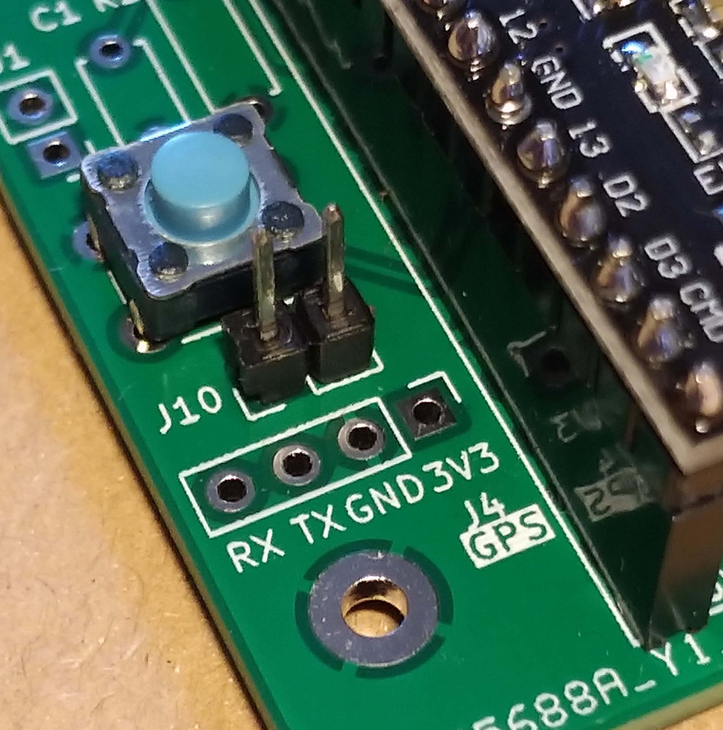
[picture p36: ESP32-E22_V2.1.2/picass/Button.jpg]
Button


### 1.6 Testlauf #1
Beim Online-Flash Tool https://esptool.oevsv.at/ ist **E22** auszuwählen. (Hat auch eine Console. Chromium Browsers only!)  
Und läuft grundsätzlich, mit Minimalbestückung und auch ohne HF (E22).  
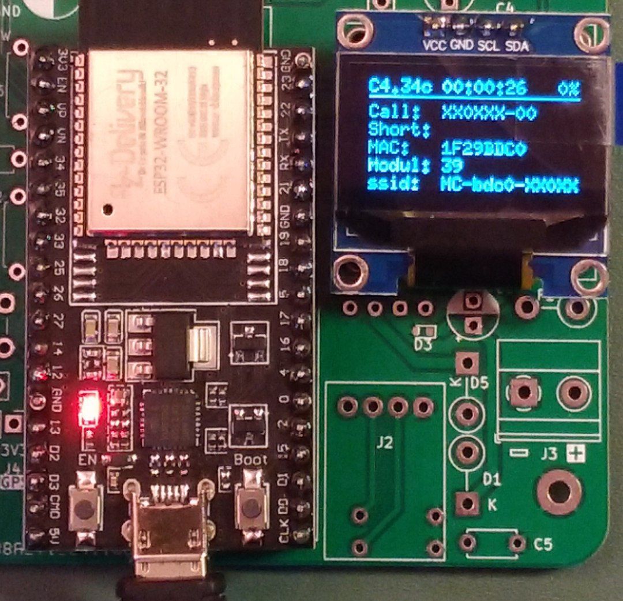
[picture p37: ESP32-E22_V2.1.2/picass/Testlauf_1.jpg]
Testlauf1


### 1.7 Varianten Antenne
* Das E22-Modul hat einen IPEX-Stecker. Hier kann eine Antenne angeschlossen werden über
  * ein **IPEX-SMA-Buchse Adapterkabel** oder
  * als Gehäusedurchführung eine dichte **U.FL IPEX <> N-Buchse** https://www.amazon.de/dp/B0C8J131PD oder
  * Alternativ eine IPEX <> SMA-Einbaubuchse: ...
 
* Beim Einbau der **SMA-Buchse J8 + R8** (0Ω=Drahtbrücke auf der Rückseite) über
  * einen SMA-St <> N-Bu mit Flansch, aber ohne Dichtung (ev. Dichtfolie verwenden):
https://www.reichelt.at/at/de/shop/produkt/hf_n_buchse_sma_flanschbuchse-141249
  * eine SMA-Bu <> SMA-Bu:  
https://www.conrad.at/de/p/bkl-electronic-0409093-0409093-sma-adapter-sma-buchse-sma-buchse-1-st-457659.html

Bei allen Varianten ist eine mechanische Entkopplung zwischen Antenne<>Gehäuse<>PCB gegeben.  

## 2) Spannungsversorgung
Für die Spannungsversorgung stehen mehrere Möglichkeiten zur Verfügung.  
### ❗ 🟡 Extrem wichtig ist aber, dass die 2x 470µF Elkos und alle 100nF KerKos bestückt sind, und dass ein Netzgerät mit ausreichender Stromergiebigkeit verwendet wird! Bei hochwertigen Netzteilen sollten 2A reichen, das die Stromspitzen auch wegpuffern kann. Besser sind Netzteile mit 3A nominell, wie sie z.B. auch für RaspberryPi verwendet werden. Und möglichst kurze und niederohmige Verbindungsleitung zwischen Netzgerät und PCB.
### ❗ 🟡 Ebenso sollte C2 10µF NICHT bestückt werden, bei Verwendung des ESP32-DevKitC-V4 Moduls!

### 2.1 USB-Micro via ESP32
Die Spannungsversorgung kann über die USB-Mikro-Buchse des ESP32-Moduls erfolgen, wenn ein geeignetes USB-Netzteil verwendet wird, welches bis zu 3A liefern kann. Mindestens jedoch 2,5A. Solche Netzteile werden z.B. auch für die Versorgung von RapberryPi u.a. verwendet.  

### 2.2 Versorgung über USB-C
Das **USB-C BreakOut-Board** mit der stehenden USB-C Buchse ermöglicht ein leichtes Anstecken der externen Versorgung, speziell bei Einbau in ein Gehäuse. https://de.aliexpress.com/item/1005007821332638.html  

<ins>**Funktion:**</ins>  
Für USB-C PD (Power Delivery) ist ein Kommunikations-IC an CC1 & CC2 erforderlich.
Wenn dieser nicht vorhanden ist, dann kann nur 5V geliefert werden und über die Widerstände an CC1 & CC2 wird der Strom "eingestellt". Die Widerstände **R3** & **R4** mit jeweils **5k1** signalisieren dem USB-Netzteils, dass es **5V/3A** liefern darf. Die Schottky-Diode **D1** verhindert eine Rückspeisung, falls mehrere Spannungsquellen angeschlossen sind.  

<ins>**Schritt 1:**</ins> Die Widerstände **R3** & **R4** (je 5k1) auf der Rückseite bestücken und auf der Oberseite Lötpins auf ein Minimum kürzen.  
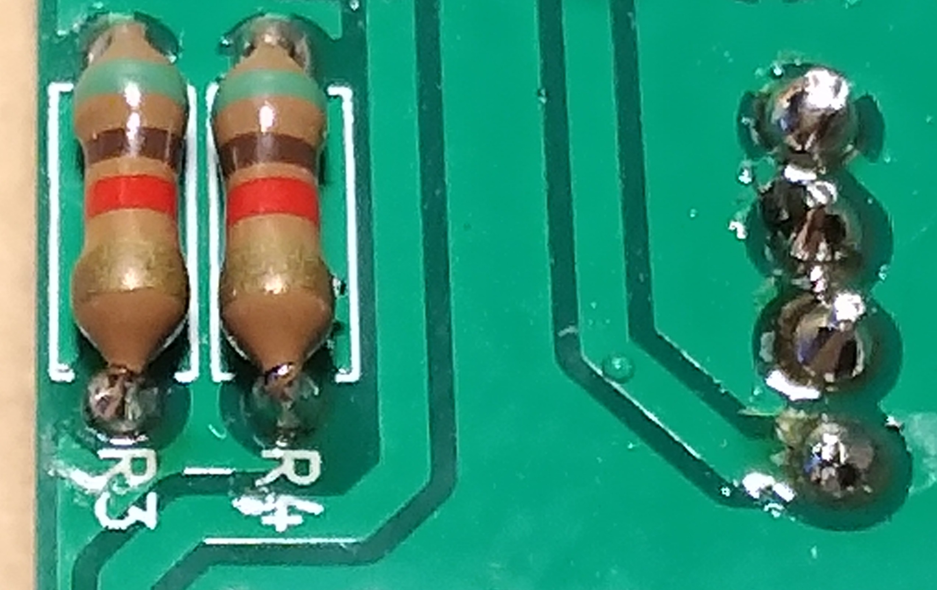
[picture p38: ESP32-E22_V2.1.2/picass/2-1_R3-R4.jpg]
R3-R4
  

<ins>**Schritt 2:**</ins> Die Diode **D1** und eine längere **4-pol** Stiftleiste **J2** mit Gesamtlänge **15mm** auf der Oberseite bestücken.  
Dann 2-3 Lagen Doppelklebepads zur Unterstützung des USB-C Adapter Boards aufbringen ...  
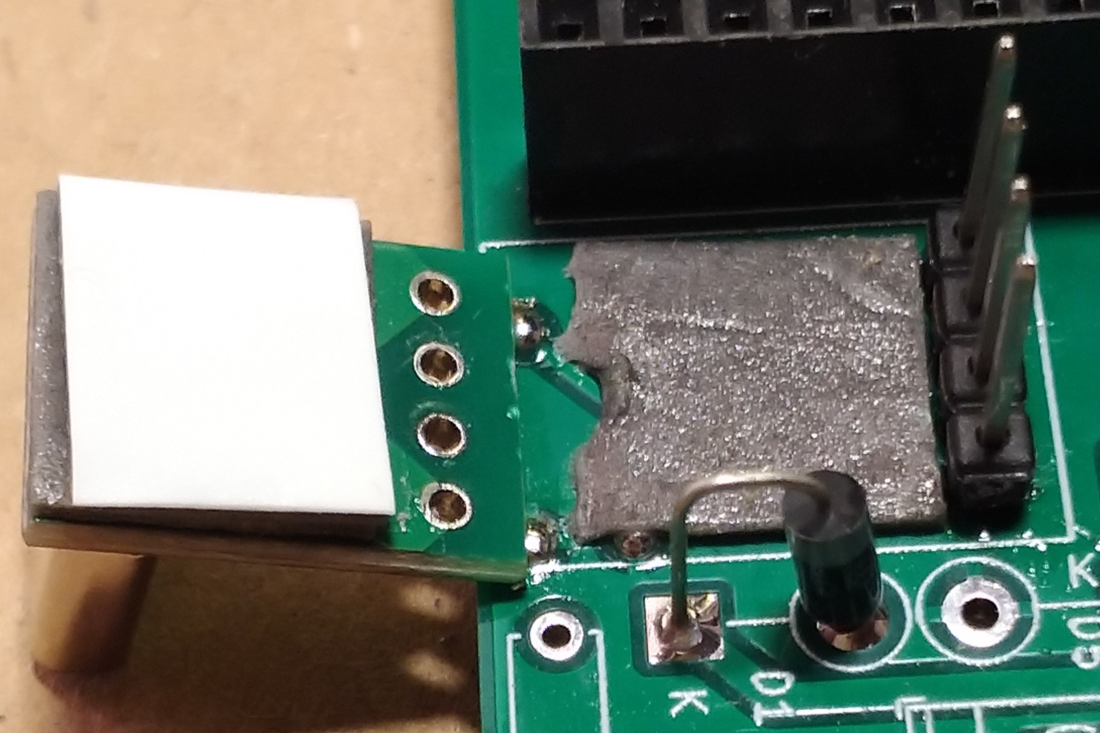
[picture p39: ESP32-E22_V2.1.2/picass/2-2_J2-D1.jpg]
J2-D1
  

<ins>**Schritt 3:**</ins> das USB-C Adapter Board aufkleben und verlöten. An die überstehende Stiftleiste kann eine USB-C Einbaubuchse mit Kabel angesteckt werden.  
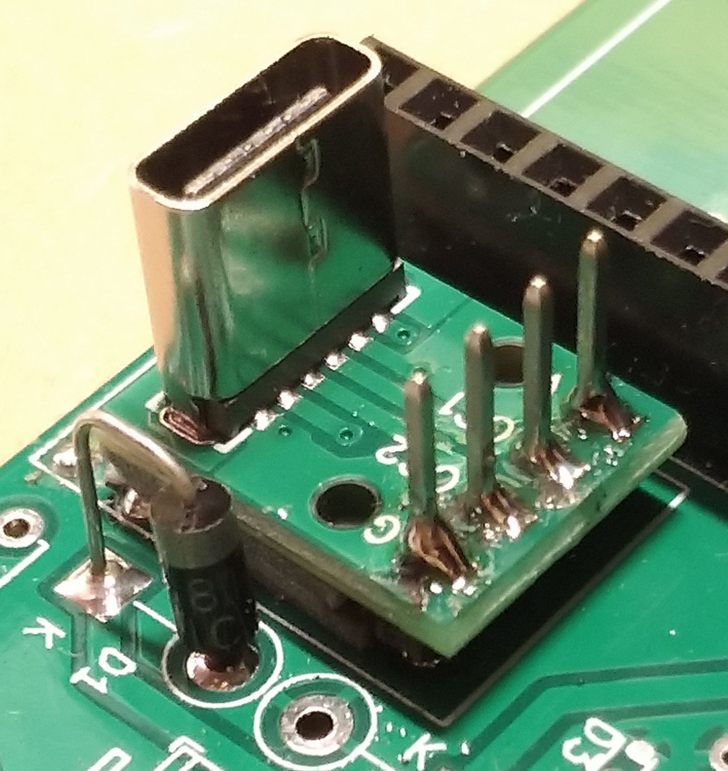
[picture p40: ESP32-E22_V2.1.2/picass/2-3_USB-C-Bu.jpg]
USB-Bu
  

Die Versorgung über die USB-C-Buchse funktioniert.  
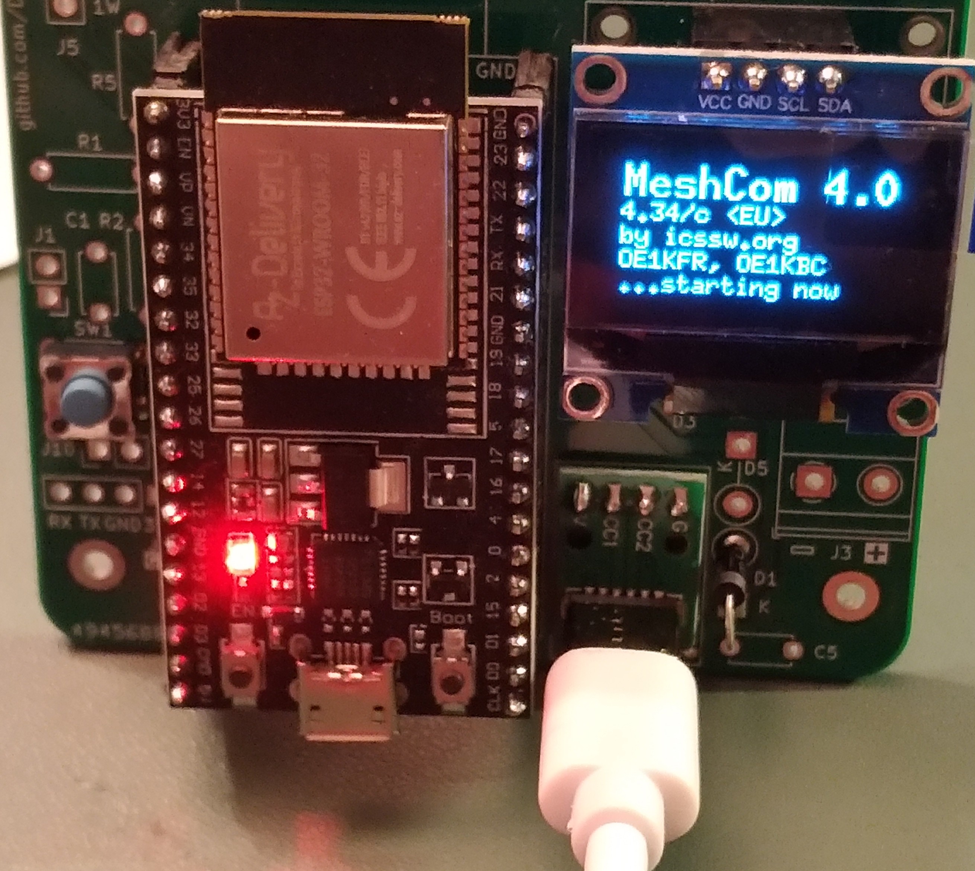
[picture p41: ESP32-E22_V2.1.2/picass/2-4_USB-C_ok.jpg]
USB-C_ok
  

### 2.3 Versorgung über DC/DC HW-613
> [!NOTE]
> Funktionsbeschreibung [!TODO]
Bei Versorgung über ein externes Netzgerät über Schraubklemmen ist zwar auch eine Schottky-Diode erforderlich, aber bei Verwendung des **DC/DC-Wandler-Boards HW-613** (bis 1,5A) kann mit bis zu 6-24V DC versorgt werden und die Ausgangsspannung kann eingestellt werden, bzw. fix durch Lötbrücken.  

**D5** 1N4007 o.ä. & **C5** 100nF bestücken  
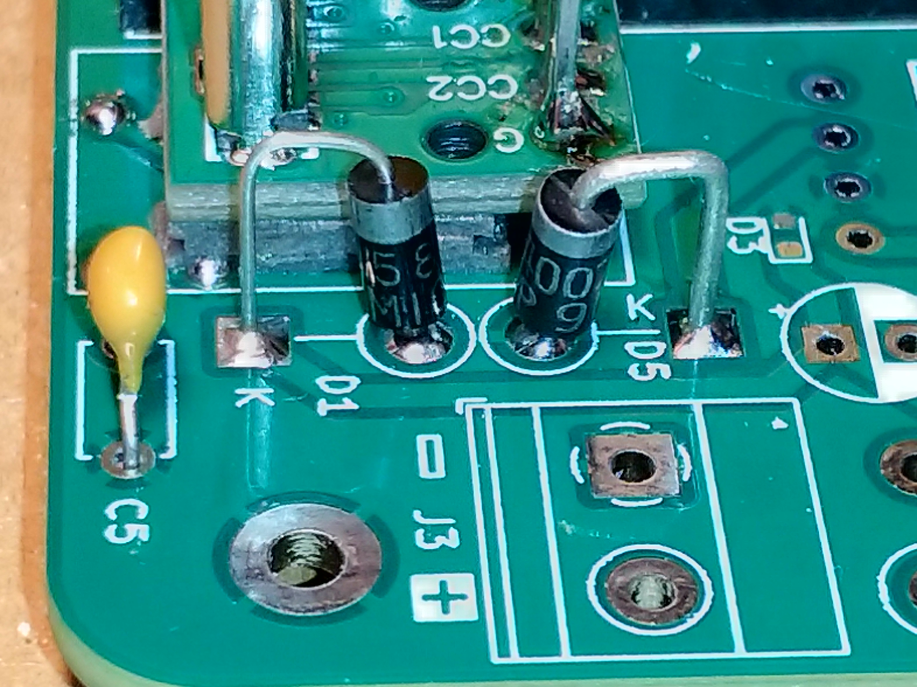
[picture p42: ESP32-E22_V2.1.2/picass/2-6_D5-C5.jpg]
D5C5
  

Eine 4-pol Stiftleiste auf den DC/DC-Wandler **U4 HW-613** löten.  
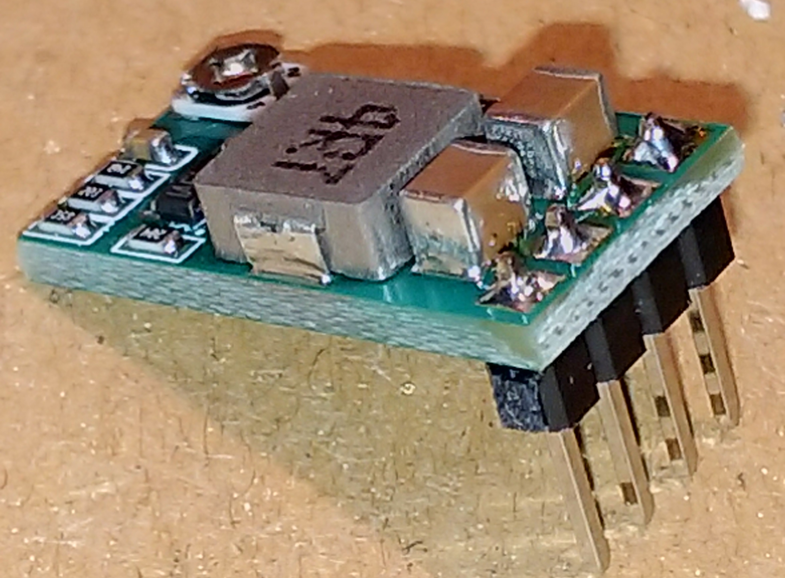
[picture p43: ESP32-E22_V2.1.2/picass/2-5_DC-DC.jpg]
DCDC
  
> [!IMPORTANT]
> Auf einem Steckbrett den DC/DC-Wandler mit dem Poti auf **5,3V** Ausgangsspannung einstellen.

> [!CAUTION]
> Es ist nicht zu empfehlen, die ADJ-Leiterbahn zu unterbrechen und den 5V-Jumper zu löten, ausser man hat ein sehr gute Lupe (Mikroskop) und entsprechendes Schneidwerkzeug. Siehe https://protosupplies.com/product/mp2315-mini-adjustable-dc-dc-step-down-module/  
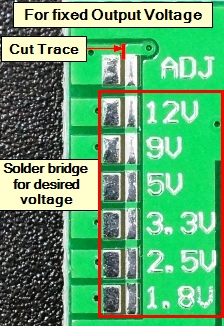
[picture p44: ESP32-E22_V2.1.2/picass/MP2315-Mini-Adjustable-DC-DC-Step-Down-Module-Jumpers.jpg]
DCDCjmp
>   

[img U4 eingelötet] & D2 auf Oberseite & J3  

Weitere BT: C6, D4 (alternativ D3)  
Weitere BT: F1, D5  
• Zusätzlich ist eine **2A** Feinsicherung **F1** und eine Schutzdiode **D5** (1N4004..1N007) gegen Verpolung eingebaut.  
• Die Transient Voltage Suppressor Diode **D4** (alternativ **D3**) schützt vor ESD mit einer VBR = 5,6V min. @ I=1mA

### 2.4 Versorgung über DC/DC R-78B5.0-2.0
Statt dem günstigen DC/DC in [2.3](https://github.com/DK9BT/esp32-e22-lora-board/blob/main/ESP32-E22_V2.1.2/PCB-Assembly/README.md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) kann auch ein handeslsüblicher, aber auch teurerer Schaltregler z.B. der **RECOM R-78B5.0-2.0** verwendet werden.  
https://at.rs-online.com/web/p/schaltregler/1392959  
https://www.conrad.at/de/p/recom-r-78k5-0-2-0-dc-dc-wandler-5-v-2-a-10-w-inhalt-1-st-2887420.html  
[img 3D]

### 2.5 Versorgung über USB-C Einbaubuchse
An die überstehende Stiftleiste **J2** kann eine USB-C Einbaubuchse mit Kabel angesteckt werden.  
[Foto !TODO]

### 2.6 weiter Versorgungsmöglichkeiten (Rohfassung aus Telegram)

❗️Ich habe viele Möglichkeiten vorgesehen. Man kann einiges weglassen, wenn man weiß, was man tut. Aber man sollte auch die Schaltung verstehen.  
1️⃣ Schraubklemme kann verwendet werden, auch ohne DC/DC. Drahtbrücke einbauen.  
2️⃣ Sicherung F1 & Diode D5 müssen nicht verwendet werden, können aber.  
3️⃣ Auf die Stiftleiste J2 kann eine USB-C Einbaubuchse angesteckt werden.

• z.B. die **6-polige (VCC GND CC1 CC2 D+ D-)**, wobei ich aber noch keine genaue Belegung dazu gefunden habe.  
grafik

• es kann auch sein, dass die **5-polige (VCC GND CC D+ D-)** funktioniert. Davon habe ich eine Belegung gefunden. Wahrscheinlich gemeinsames CC, also CC1-CC2 verbunden, was aber zu dem bekannten RPi-Problem führt.
grafik

❌ Die **2-poligen (nur VCC & GND)** und die **4-poligen (VCC & GND & D- & D+)** funktionieren aber definitiv NICHT, da die CC1 & CC2 Anschlüsse fehlen und daher von dem USB-C Netzteil nur 5V/500mA bereitgestellt werden darf, außer ev. Ausnahmen, wenn man "dumme" Netzteile u/o "dumme" USB-C Anschlusskabel verwendet.

## 3) Einbau in ein Gehäuse
Enclosure (transparent) https://www.reichelt.de/de/de/shop/produkt/industriegehaeuse_120_x_80_x_60_2mm_ip65_lichtgrau-340524  
Enclosure (non-transparent) https://www.reichelt.de/de/de/shop/produkt/industriegehaeuse_120_x_80_x_60_2mm_ip65_lichtgrau-340515  
Gehäuse Maßzeichnung: https://cdn-reichelt.de/documents/datenblatt/C700/6U07120806437_6U-120806_DB.pdf  

* Das Gehäuse verfügt über 8 Stk. Sacklöcher Ø3,2x4. Die in den Ecken sind für die Befestigung der PCB vorgesehen. Die Sacklöcher auf den Seiten können für die Befestigung eines 3D-Druck Einbauteils verwendet werden.
* Darin können **M2x4x3,5 Einpressmutter** eingeschmolzen werden, wenn keine Schraubklemme+DC/DC-Wandler verwendet werden.
* Bei Verwendung der Schraubklemme + DC/DC-Wandler, der auf der Rückseite der PCB platziert ist, muss ein größerer Abstand der PCB vom Gehäuseboden durch Verwendung von **M2x6x3,5 Einpressmuttern** eingehalten werden.
* Alternativ können auch Abstandsröhrchen L≥1,5mm verwendet werden (z.B. Ms-Rohr Ø3) und M2x8 Schrauben.
* !!! für den erhöhten Einbau der PCB ins Gehäuse wird es ein 3D-Druck-Teil geben!
* Bei anderem Bedarf können aber auch die Befestigungsbohrungen auf der PCB aufgebohrt werden.  
Einpressbuchse_M2x4x3,5  

Für das wasserdichte Gehäuse ist eine Druckausgleichsmembran zu empfehlen, damit das Wasser auch wieder herausdiffundieren kann. Sonst steht irgendwann die Leiterplatte unter Wasser.  
z.B. https://shop.bb-sensors.com/Druck/Drucksensoren/Druckausgleich-Membran-VPE-12-Stueck.html  
oder https://www.reichelt.at/at/de/shop/produkt/druckausgleichselement_m12_schwarz_2_stueck-371154  
oder https://www.amazon.de/dp/B088QJG676

Je nach Aufstellungsort kann auch eine einfache ≈Ø2mm Bohrung zum Druckausgleich ausreichen.  

### 3.1 Programmierkabel für ESP32
Dieses könnte wegen der nur 20cm im Gehäuse verbleiben:  
https://www.reichelt.at/at/de/shop/produkt/dual_easy_usb_2_0_kabel_a_st_auf_micro_b_st_gew_0_2_m-287766  
oder es kann ein Winkeladapter verwenden werden: https://www.amazon.de/dp/B0CRVH7JRD  

## 4) Sensoren
### 4.1 GPS
GPS wird hier am **J4** angesteckt. Für die GPS-Antenne ist "rechts oben" neben der SMA-Buchse die Platine ausgespart. Da ist Platz im Gehäuse, die Antenne parallel zur Seitenwand anzubringen.  
Hierfür wurde von **DF2PI** ein 3D-Druckteil entworfen:  
https://www.printables.com/model/1135886-montagebrucke-interne-gps-antenne-gps-board-fur-me  

grafik

grafik

In der `configuration.h`  
`#define GPS_RX_PIN 16` **<= TX am GPS-Modul**  
`#define GPS_TX_PIN 17` **=> RX am GPS-Modul**

### 4.2 BME/BMP 280
Hier ist **J6** vorgesehen.  
Sensor **BME280 Board 10,5 x 13,2 mm**
- Ein  **BME280** hat ein fast quadratisches Gehäuse mit Luftloch in der Mitte. (Im Gegensatz zu einem **BMP280**, der ein rechteckiges Gehäuse mit Luftloch in einer Ecke hat.)
- Da der Chip von 1,8 .. 3,3V (4,25V max.) funktioniert und - wie ersichtlich - ein LDO + Level-Shifter auf der Rückseite sind, sind diese Ausführungen für 3,3V und auch 5V geeignet.
- im linken Bild oberhalb der Beschriftung sind 3 Pads: hier kann die I²C-Adresse auf 0x77 geändert werden, wenn das mittlere Pad mit dem linken - offenbar GND - verbunden wird. Wenn nach VDD (rechts) oder offen, dann std. 0x76.
- Ein **BME280** misst **interne Chip-Temperatur, Druck und Luftfeuchtigkeit**.  
grafik
grafik

### 4.3 INA226
Hier ist **J7** vorgesehen. ❗ versetzt an 5-pol J7 anstecken. Die Bohrung oberhalb ist für mechanische Befestigung des Boards gedacht, wenn das Board horizontal eingebaut wird.  
Mit dem Befehl `--shunt {0.001 .. 0.5}` kann der Shunt-Widerstand des INA226-Moduls definiert werden. Kann auch zur Kalibrierung verwendet werden.  
grafik

___
## 98) weitere Hinweise
* **C2** ist bei Verwendung des **ESP32-DevKitC-V4** nicht erforderlich. Die Anschlüsse können für einen externen Reset-Taster verwendet werden.
* **R1, R2, C1, J1** nur dann bestücken, wenn man eine Spannung messen will. Hierfür sind die Widerstände, dh. der Spannungsteiler,
 so zu wählen, dass die Spannung am ADC-Eingang des ESP32 max. 3,2V erreicht.
* **R6 & R7** (PullUp-Widerstände für I²C-Bus) nur dann bestücken, wenn Probleme mit I²C-Komponenten auftreten. Hierbei aber feststellen, ob die verbundenen I²C-Boards schon selber PullUp-Widerstände enthalten.

___
# 99) Allgemeine Hinweise
* Die Schaltung ist nach den gängigen Regeln der Technik konzipiert und hergestellt. Es wurde jedoch nicht geprüft ob allfällige Normen eingehalten werden.
* Die hier angegebenen Hinweise sind lediglich eine Beschreibung einer Möglichkeit des Zusammenbaus.
* Die Inbetriebnahme erfolgt eigenverantwortlich.
* Ich weise auf die gesetzlichen Bestimmungen bez. Elektrogeräten, Funkanlagen u.ä. hin, die von jedem Anwender selber einzuhalten sind.

___
***:copyright: 24.11.2025 10:10 by OE3WAS - Wolfgang***

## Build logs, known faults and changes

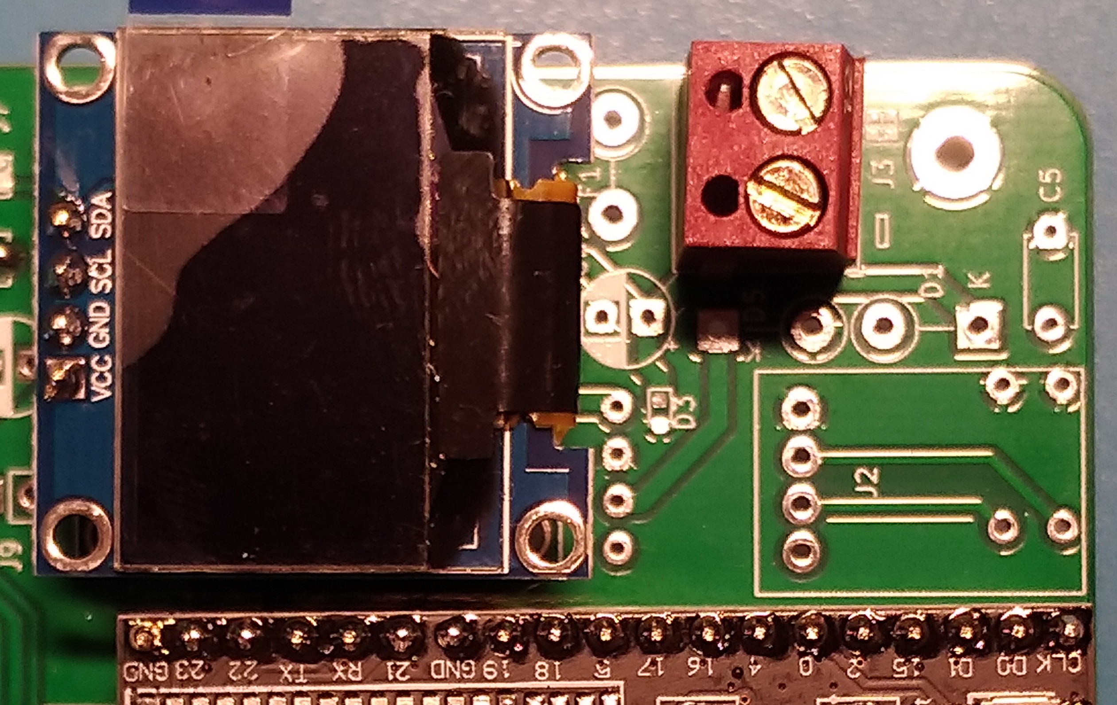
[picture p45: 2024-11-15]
ESP32-E22_V2.1.2/picass/Problem_F1.jpg

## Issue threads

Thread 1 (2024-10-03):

OE3WAS V2.0.1

karamo, 2024-10-03:
1. Schritt: Schaltung kl. Fehler bereinigt und Darstellung verbessert.
[esp32-e22_v2.0.1.zip](https://github.com/user-attachments/files/17247714/esp32-e22_v2.0.1.zip)

karamo, 2024-10-03:
durch V2.0.2 ersetzt

Closed 2024-10-03.

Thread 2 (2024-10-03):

OE3WAS V2.0.2

karamo, 2024-10-03:
2. Schritt: weitere Verbesserung der Darstellung und Ergänzungen.
[esp32-e22_v2.0.2.zip](https://github.com/user-attachments/files/17249293/esp32-e22_v2.0.2.zip)

DK9BT, 2024-10-04:
merged to main

Closed 2024-10-04.

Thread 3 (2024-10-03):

ESP32-E22_OE3WAS_V2.0.3

karamo, 2024-10-03:
neue Version: Fehlerbehebung
[ESP32-E22_OE3WAS_V2.0.3.pdf](https://github.com/user-attachments/files/17250256/ESP32-E22_OE3WAS_V2.0.3.pdf)
[esp32-e22_v2.0.3.zip](https://github.com/user-attachments/files/17250257/esp32-e22_v2.0.3.zip)

karamo, 2024-10-03:
In der nächsten Version sind:
1) Footprint für Schraubklemme schon gefunden.
2) Beschriftung der Steckerleisten vollständig.

Offen ist nur noch die Frage, ob auf EN = RESET ein zusätzlicher Elko erforderlich wäre.
Taster ist nicht notwendig, da auf dem ESP32-Board.

DK9BT, 2024-10-04:
merged to main

Closed 2024-10-04.

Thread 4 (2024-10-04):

Problem: PCB ändern

karamo, 2024-10-04:
Im Leiterplatteneditor kann man mit "d" Bauteile mit angehängten Leiterbahnen verschieben.
Aber beim Rotieren reissen die Bahnen ab.
[esp32-e22_problem.zip](https://github.com/user-attachments/files/17259130/esp32-e22_problem.zip)

karamo, 2024-10-04:
💩 das ist bereits seit 2 Jahren beschrieben und gewünscht:
https://gitlab.com/kicad/code/kicad/-/issues/9672

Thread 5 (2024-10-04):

SCH V 2.0.6 & PCB V 2.0.1

karamo, 2024-10-04:
[esp32-e22-lora-board_2.0.6.zip](https://github.com/user-attachments/files/17263653/esp32-e22-lora-board_2.0.6.zip)

**SCH V 2.0.6** ist so weit mal fertig
[esp32-e22-lora-board_2.0.6.pdf](https://github.com/user-attachments/files/17263654/esp32-e22-lora-board_2.0.6.pdf)

**PCB V 2.0.1** steht zur Diskussion
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

karamo, 2024-10-04:
von Ben:
Ich frag mich ob wir noch Richtung Gehäuse mal schauen sollten? Irgendwas günstiges schönes...wenn die Bohrlöcher für Gehäuse XY schon passen dann hilft das dem einen oder anderem OM sicher....dann muss die Platine auch net im Müllbeutel oder Brotdose außen am Fenster hängen 😂

karamo, 2024-10-04:
Ja, sucht was aus. PCB kann ich ja dementsprechend anpsssen.

karamo, 2024-10-04:
für den SMA-Buchsen Anschluss siehe hier:

https://www.mikrocontroller.net/topic/218948

https://www.mantaro.com/index.php/resources/impedance-calculator.htm

karamo, 2024-10-05:
offene Punkte:
• 3D Modelle von den Modulen u.a. Bauteilen.
• und mit den Leiterbahnbreiten bin ich auch noch nicht überall zufrieden.
• spezielle Platzierung der I²C (2 rechts hinten) ist auch nur mal so.
• Befestigungsbohrungen fehlen natürlich auch noch.
• vorverbundene Jumper für I²C Display in default pinning

karamo, 2024-10-05:
OLED
https://github.com/pforrmi/KiCad-SSD1306-128x64
https://www.snapeda.com/parts/DM-OLED096-636/Display%20Module/view-part/
https://forum.kicad.info/t/oled-display-1x4-header-and-four-soldered-threaded-standoff-footprint-versus-bom/46372
https://github.com/TG9541/kicad-footprints
https://www.youtube.com/watch?v=iLqMU6PnAjU

karamo, 2024-10-05:
SMA
https://kicad.github.io/footprints/Connector_Coaxial
https://www.snapeda.com/parts/221789-1/TE%20Connectivity/view-part/
https://www.snapeda.com/parts/CON-SMA-EDGE-S/RF%20Solutions/view-part/

karamo, 2024-10-05:
ESP32 DevKit V4
https://www.snapeda.com/parts/ESP32-DEVKITC-32D/Espressif%20Systems/view-part/
https://grabcad.com/library/esp32-devkitc-v4-1

karamo, 2024-10-05:
OneWire benötigt einen 4k7 Ω Widerstand
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

karamo, 2024-10-05:
Schottky-Dioden & Schutzdioden am Versorgungsspannungseingang USB-C & Schraubklemme vorsehen.
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

DK9BT, 2024-10-06:
v2.0.6 commited to git

Closed 2024-10-06.

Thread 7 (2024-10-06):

SCH V 2.0.7 & PCB V 2.0.2

karamo, 2024-10-06:
[esp32-e22_SCH-2.0.7.pdf](https://github.com/user-attachments/files/17269866/esp32-e22_SCH-2.0.7.pdf)
[esp32-e22_PCB-2.0.2_3D.pdf](https://github.com/user-attachments/files/17269867/esp32-e22_PCB-2.0.2_3D.pdf)
[esp32-e22_SCH-2.0.7_PCB-2.0.2.zip](https://github.com/user-attachments/files/17269871/esp32-e22_SCH-2.0.7_PCB-2.0.2.zip)

karamo, 2024-10-06:
**offene Punkte:**
• Leiterbahnführung & Leiterbahnbreiten optimieren.
• 50Ω Stripline für SMA-Anschluss
• spezielle Platzierung der I²C-Verbinder für BME & Reserve.
• Versorgungen mit Schutzdioden siehe Kommentar.
• Befestigungsbohrungen für Gehäuse & OLED

**von Ben:**
Ich frag mich ob wir noch Richtung Gehäuse mal schauen sollten? Irgendwas günstiges schönes...wenn die Bohrlöcher für Gehäuse XY schon passen dann hilft das dem einen oder anderem OM sicher....dann muss die Platine auch net im Müllbeutel oder Brotdose außen am Fenster hängen 😂

• Wasserdichte Anschlussdose, IP65 Elektrische Projektbox Verteilerdose Staubdicht Wetterfest, ABS Kabelgehäuse Verteilerkasten für Indoor Outdoor Elektronikkabel (Transparent 15,8 x 9 x 6,4 cm)
[https://amzn.eu/d/4mfVIbA](https://amzn.eu/d/4mfVIbA)

• andere Gehäuse
Aussengehäuse http://www.schubert-gehaeuse.de/aussengehaeuse.html

Weissblechgehäuse http://www.schubert-gehaeuse.de/weissblechgehaeuse.html

karamo, 2024-10-06:
Schottky-Dioden & Schutzdioden am Versorgungsspannungseingang USB-C & Schraubklemme vorsehen.
Als Vorlage dient der Versorgungsteil am ESP32-Board.
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

https://www.snapeda.com/parts/LESD5D5.0CT1G/Leshan%20Radio%20Co./view-part/
https://de.aliexpress.com/i/1005005640352091.html

https://www.snapeda.com/parts/1N5817/Taiwan%20Semiconductor/view-part/

https://www.snapeda.com/parts/BAT760-7/Diodes%20Inc./view-part/

DK9BT, 2024-10-07:
commited to git

Closed 2024-10-08.

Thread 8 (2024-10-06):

Gehäuse

DK9BT, 2024-10-06:
Gehäusevorschläge:

https://www.amazon.de/dp/B08XNMZF2V

Vorteil: Ohne Schraubendreher zu öffnen....Transparent für Display -> universell

Platine: 132x80 mm passt genau rein mit 2  M5 Gewinden zur Befestigung

DK9BT, 2024-10-06:
oder eines mit Schrauben:
https://www.amazon.de/dp/B0CZ6CYHLS

karamo, 2024-10-06:
• Wasserdichte Anschlussdose, IP65 Elektrische Projektbox Verteilerdose Staubdicht Wetterfest, ABS Kabelgehäuse Verteilerkasten für Indoor Outdoor Elektronikkabel (Transparent 15,8 x 9 x 6,4 cm)
https://amzn.eu/d/4mfVIbA

• andere Gehäuse
Aussengehäuse http://www.schubert-gehaeuse.de/aussengehaeuse.html

Weissblechgehäuse http://www.schubert-gehaeuse.de/weissblechgehaeuse.html

Closed 2024-10-07.

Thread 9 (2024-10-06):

SCH V 2.0.8 & PCB V 2.0.3

karamo, 2024-10-06:
• für Schutzbeschaltung vorbereitet
• Routing verbessert & Leiterbahnbreiten 0,2 -> 0,3mm
[esp32-e22_SCH-2.0.8_PCB-2.0.3.zip](https://github.com/user-attachments/files/17271071/esp32-e22_SCH-2.0.8_PCB-2.0.3.zip)

DK9BT, 2024-10-07:
commited to git

Closed 2024-10-07.

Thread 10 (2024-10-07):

SCH V 2.0.9 & PCB V 2.0.4 - Alpha-Version

karamo, 2024-10-07:
Die grundsätzliche Funktion sollte gegeben sein.

**KiCad Projekt:**
[esp32-e22_SCH-2.0.9_PCB-2.0.4.zip](https://github.com/user-attachments/files/17284770/esp32-e22_SCH-2.0.9_PCB-2.0.4.zip)

karamo, 2024-10-07:
**Offene Fragen / Probleme, die in der nächsten Version behoben werden:**

• das 3D-Modell der SMA-Bu ist bei der Modifikation verschwunden.
• In der SCH fehlen noch die Typen der Schutzbeschaltung.
• Die Frage ist auch, ob der USB-C Stecker wegen der größeren Ausnehmung rechts vorne vom Gehäuse überhaupt einsteckbar ist.

• Gehäusedaten in Doku

karamo, 2024-10-08:
**Erläuterungen zum Gehäuseeinbau:**

Das Gehäuse verfügt über Ø3,2x4 Sacklöcher. Darin können M2x4x3,5 Einpressmutter eingeschmolzen werden.
Bei anderen Bedarf können die Befestigungsbohrungen auf der PCB aufgebohrt werden.
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

Durch die stehende SMA-Buchse ist eine mechanische Entkopplung von Gehäuse-PCB-Montage zu einer ev. am Gehäuse montierter Antennen-Buchse gegeben.

Das Breakout Board mit der stehenden USB-C Buchse ermöglicht ein leichtes Anstecken der externen Versorgung.
https://de.aliexpress.com/item/1005007821332638.html

HelmiBeh, 2024-10-09:
Ich würde in die Leitung vom Pin21 vom E22 zur Antennenbuchse noch einen 0-Ohm-SMD-Widerstand (0805) einbauen. Dann kann man Leitung bei Verwendung der u-Fl-Buchse abtrennen. Bei Verwendung der SMA reicht ein kleiner Lötklecks.

karamo, 2024-10-10:
> Wenn man die Bauteile in SMD machen würde, könnte man das Kleinvieh gleich beim Leiterplattenhersteller bestücken lassen. Und 1206 oder 0805 kann man auch im Alter noch gut per Hand löten.

wäre zwar zu überlegen, aber die PCB schaut auch mit den bedrahteten Bauteilen jetzt sehr aufgeräumt aus und es ist (noch) genügend Platz dafür.
die USB-C als SMD ist auch bereits verschwunden und sind nur 4 Pins, an die man wahlweise verschiedene Teile anschließen kann. Infos hierzu folgen in den nächsten Tagen.
Somit verbleibt nur optional die eine Transient Supressor Diode als SMD.

Closed 2024-10-09.

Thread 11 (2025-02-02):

Use of this design with rnode and Meshchat

pa2eon, 2025-02-02:
Dears,

Found your very nice hardware design .. of the Rnode hardware with the ESP32 and E22-400M33 RF module.

Is it possible to use this hardware with the 'firmware' from  Markqvist:  https://markqvist.github.io/Reticulum/manual/interfaces.html
In the Netherlands and Belgium we have started the new design pages on http://www.hamesh.eu

Many regards,

PA2EON - Eric

DK9BT, 2025-02-03:
This is free hardware so you can do whatever you want with that.

But i would asume the project you mentioned is not for Ham-Radio cause it includes encryption and thats basicly prohibited on ham frequencies.

But have a look at MeshCom....thats the "normal" firmware which runs on our board and provides mesh comunication for hams

https://icssw.org/meshcom/

https://github.com/icssw-org/MeshCom-Firmware/

karamo, 2025-02-03:
> Is it possible to use this hardware with the 'firmware' from Markqvist: https://markqvist.github.io/Reticulum/manual/interfaces.html In the Netherlands and Belgium we have started the new design pages on http://www.hamesh.eu

durchaus möglich - quite possible

karamo, 2025-02-03:
> the Rnode

Yes, I know Rnode and ported the FW years ago to ESP32.
But I do not give any support to use my PCB for it.

Ja, ich kenne RNode und habe die FW vor Jahren nach ESP32 portiert.
Aber ich gebe keine Unterstützung, um mein PCB dafür einzusetzen.

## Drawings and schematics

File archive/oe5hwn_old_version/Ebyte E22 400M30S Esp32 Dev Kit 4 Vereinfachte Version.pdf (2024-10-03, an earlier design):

# GND Ebyte E²² M⁴⁰⁰S³⁰

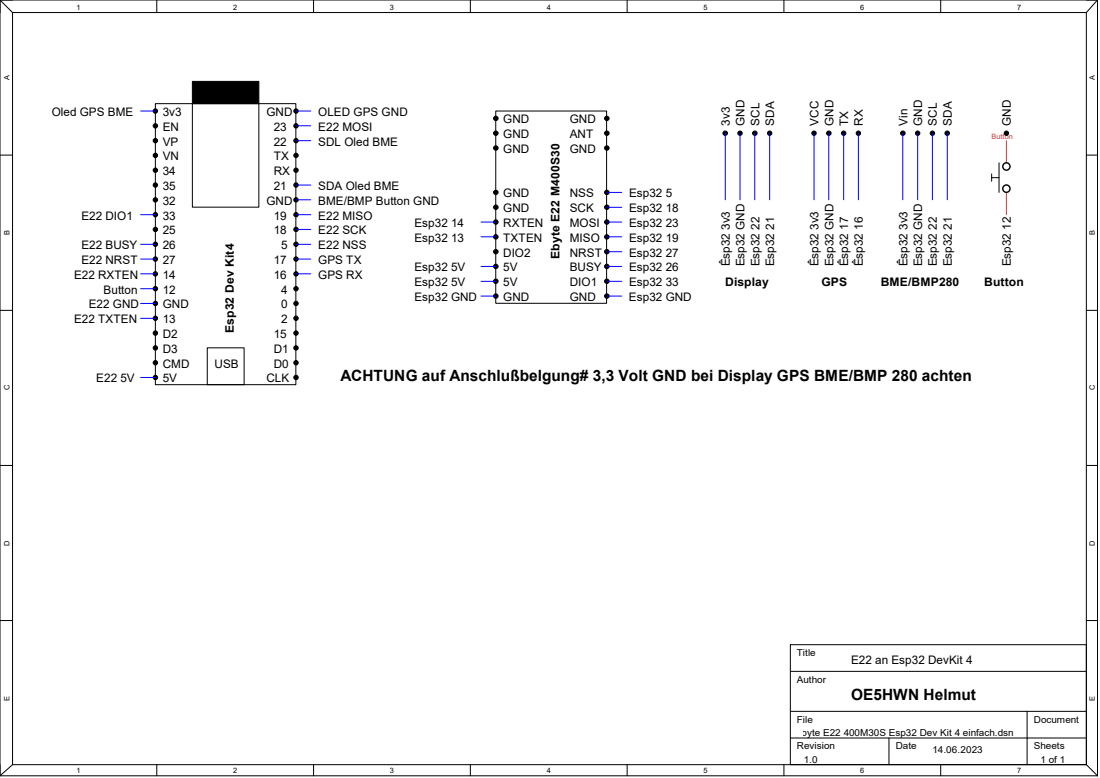
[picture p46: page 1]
CMD; GND; GND 23 22 TX RX; CLK; USBEsp32 Dev Kit4; GND GND GND; ANT; NSS SCK MOSI MISO NRST BUSY DIO1; Display; GPS; BME/BMP280 VCC; Vin Esp32 GND SCL SDA; TXRX; SCL SDA Êsp32 3v3; GND Esp32 22 Esp32 21 3v3 GND; Êsp32 3v3 Esp32 GND; Êsp32 3v3 Esp32 GND Esp32 22 Esp32 21 Esp32 13; Esp32 GND; Esp32 5V; DIO2; TXTEN; RXTEN; GND GND; Esp32 14; Esp32 33; Esp32 26; Esp32 27; Esp32 19; Esp32 23; Esp32 18; Esp32 5; Êsp32 17 Êsp32 16; E22 GND; E22 NRST; E22 BUSY; E22 DIO1; E22 TXTEN; E22 RXTEN Button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

Oled GPS BME

Button ButtonEsp32 12 GNDOLED GPS GND
E22 MOSI
SDL Oled BME

SDA Oled BME
BME/BMP Button GND
E22 MISO
E22 SCK
E22 NSS
GPS TX
GPS RX

ACHTUNG auf Anschlußbelgung# 3,3 Volt GND bei Display GPS BME/BMP 280 achten

File
... Ebyte E22 400M30S Esp32 Dev Kit 4 einfach.dsn
Revision

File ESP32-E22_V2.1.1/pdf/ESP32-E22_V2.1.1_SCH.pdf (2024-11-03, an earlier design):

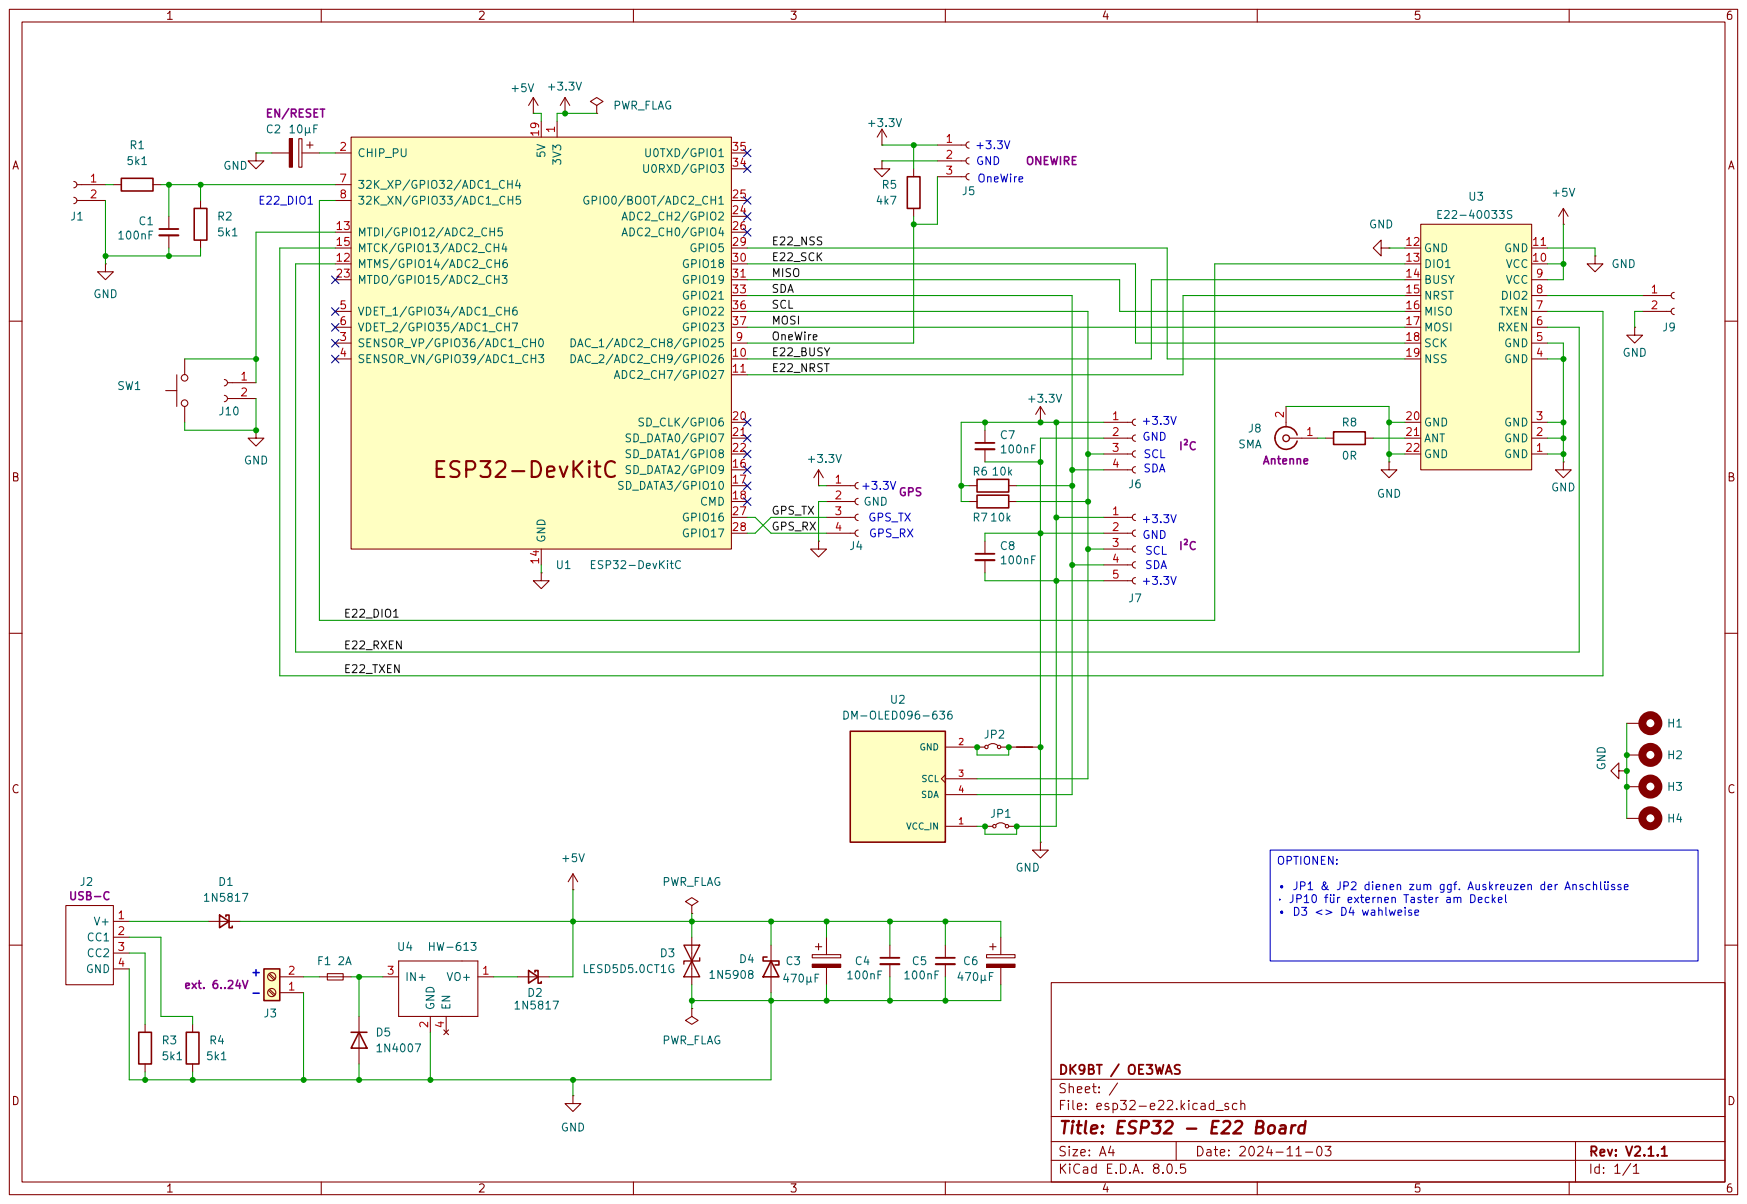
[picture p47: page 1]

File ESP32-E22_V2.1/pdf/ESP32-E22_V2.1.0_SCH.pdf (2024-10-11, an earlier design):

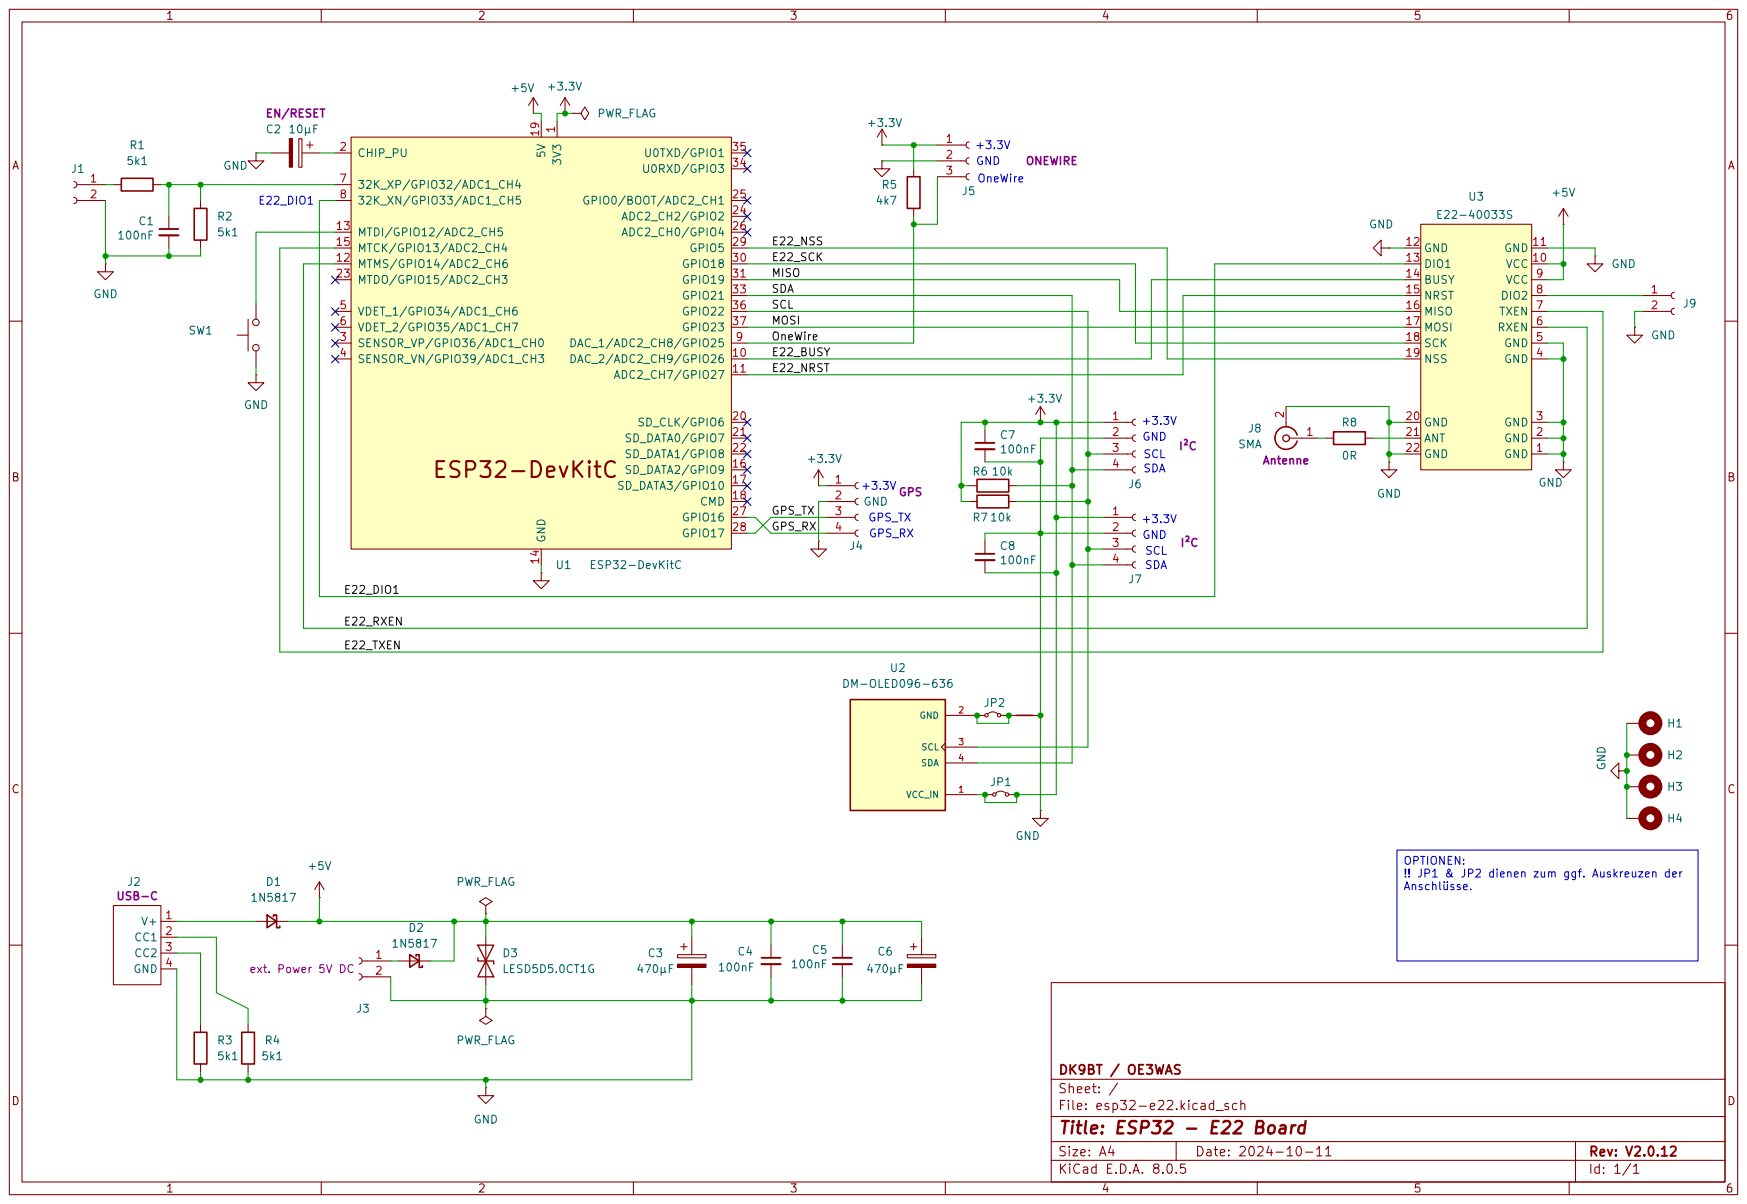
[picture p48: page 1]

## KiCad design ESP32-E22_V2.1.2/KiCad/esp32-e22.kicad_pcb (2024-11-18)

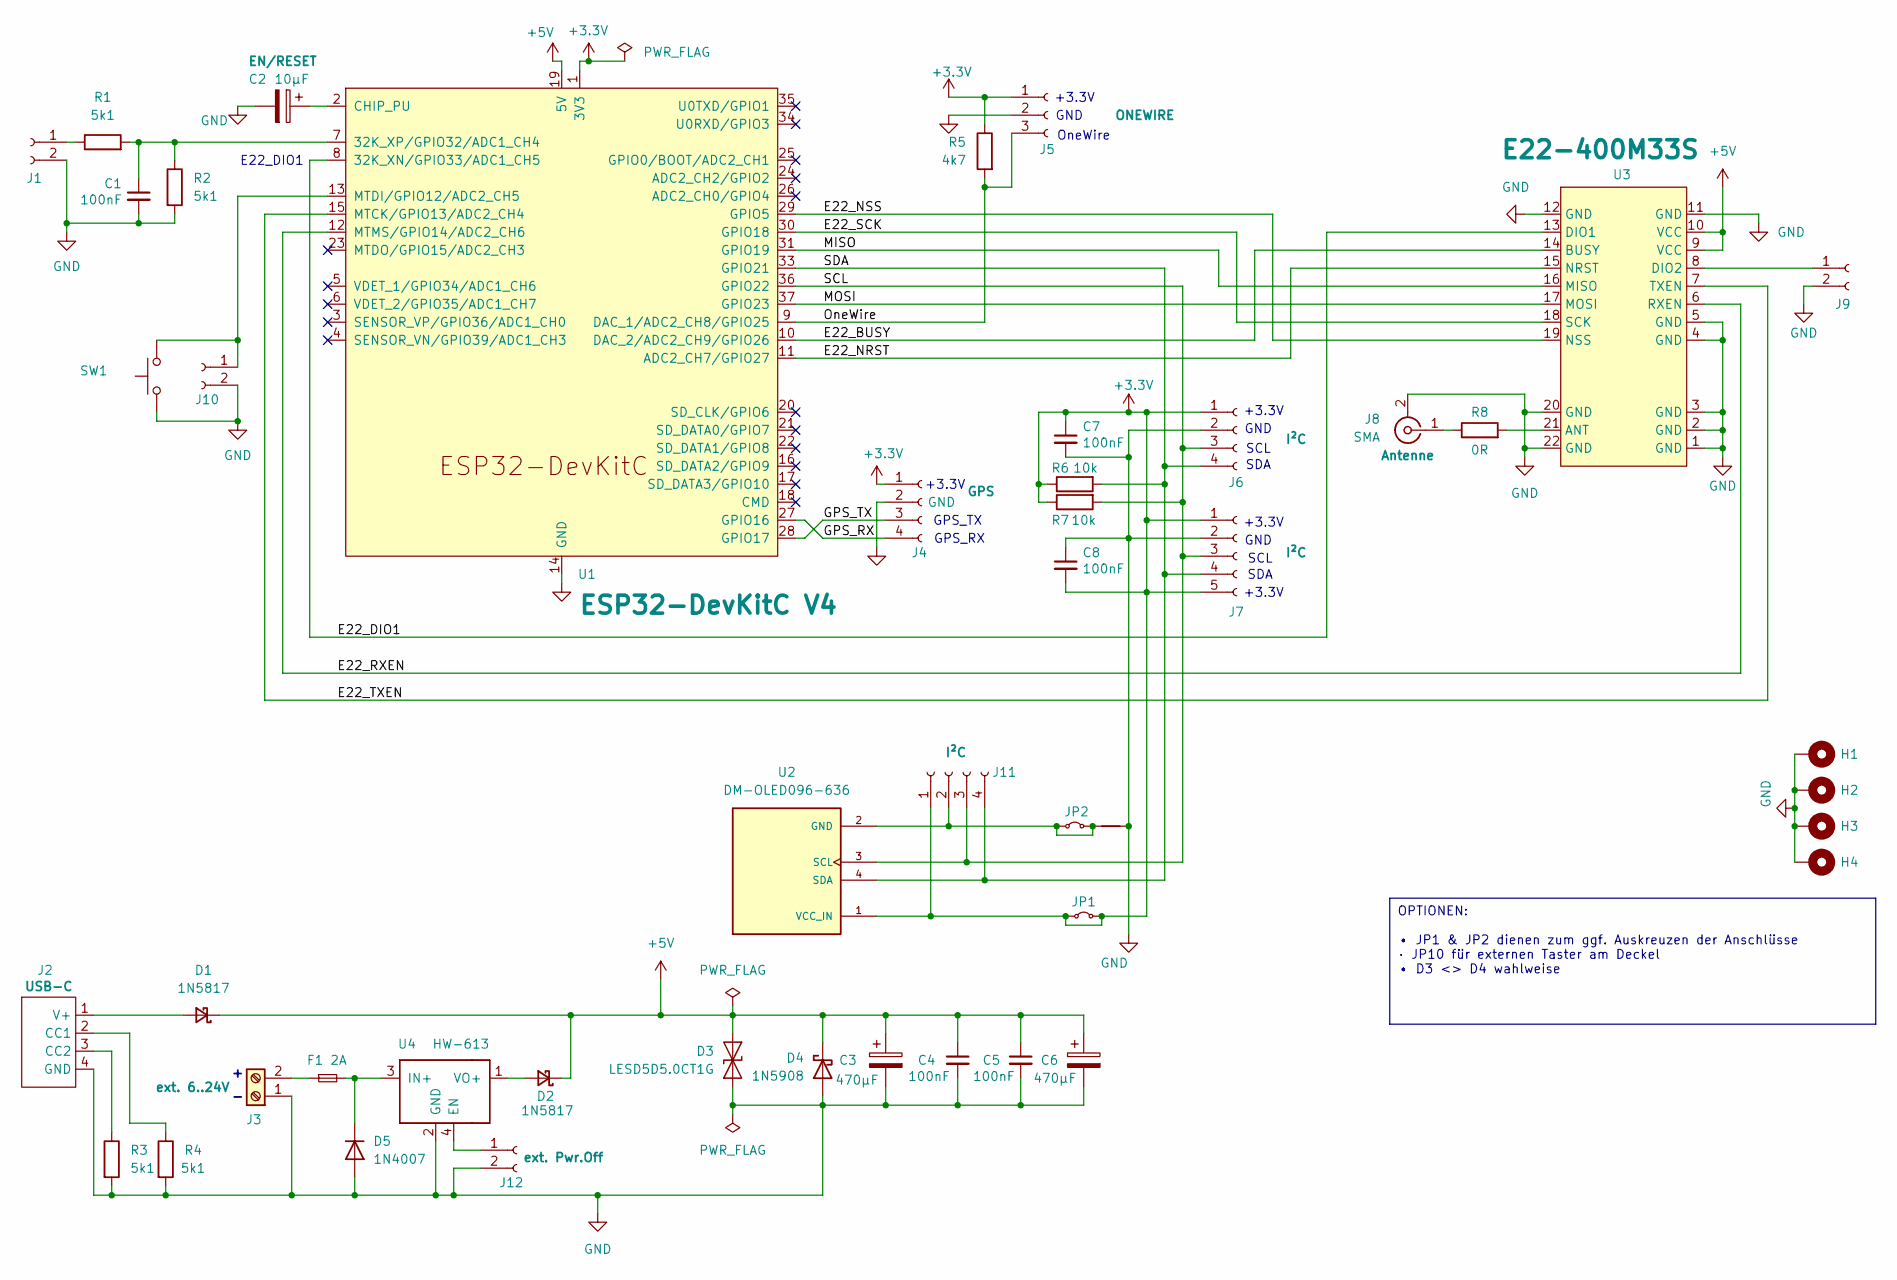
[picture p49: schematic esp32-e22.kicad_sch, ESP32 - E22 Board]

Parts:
C1, C4, C5, C7, C8: 100nF; C_Disc_D4.7mm_W2.5mm_P5.00mm
C2: 10µF; CP_Radial_D6.3mm_P2.50mm
C3, C6: 470µF; CP_Radial_D5.0mm_P2.50mm
D1: 1N5817; D_DO-41_SOD81_P5.08mm_Vertical_KathodeUp
D2: 1N5817; D_DO-41_SOD81_P7.62mm_Horizontal
D3: LESD5D5.0CT1G; D_SOD-523
D4: 1N5908; D_DO-201_P12.70mm_Horizontal
D5: 1N4007; D_DO-41_SOD81_P2.54mm_Vertical_KathodeUp
F1: 2A; R_Axial_DIN0411_L9.9mm_D3.6mm_P5.08mm_Vertical
H1, H2, H3, H4: MountingHole_Pad; MountingHole_2.2mm_M2_Pad_TopBottom
J1, J9, J10: Conn_01x02_Socket; PinHeader_1x02_P2.54mm_Vertical
J2: USB-C_vert
J3: Screw_Terminal_01x02; TerminalBlock_Phoenix_MKDS-1,5-2-5.08_1x02_P5.08mm_Horizont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
J4: Conn_01x04_Socket; PinHeader_1x04_P2.54mm_Vertical
J5: Conn_01x03_Socket; PinHeader_1x03_P2.54mm_Vertical
J6, J11: Conn_01x04_Socket; PinSocket_1x04_P2.54mm_Vertical
J7: Conn_01x05_Socket; PinSocket_1x05_P2.54mm_Vertical
J8: SMA; SMA_Amphenol_901-143_Horizontal
J12: Conn_01x02_Socket; PinHeader_1x02_P2.54mm_Horizontal
JP1, JP2: Jumper_2_Small_Bridged; TestPoint_2Pads_Pitch2.54mm_Drill0.8mm
NT1: NetTie_2; NetTie-2_SMD_Pad0.5mm
R1, R2, R3, R4: 5k1; R_Axial_DIN0207_L6.3mm_D2.5mm_P7.62mm_Horizontal
R5: 4k7; R_Axial_DIN0207_L6.3mm_D2.5mm_P7.62mm_Horizontal
R6, R7: 10k; R_Axial_DIN0207_L6.3mm_D2.5mm_P7.62mm_Horizontal
R8: 0R; R_0805_2012Metric
SW1: SW_Push; SW_PUSH_6mm
U1: ESP32-DevKitC V4; ESP32-DevKitC
U2: DM-OLED096-636; PARTREV 2018-09-10
U3: E22-400M33S
U4: HW-613

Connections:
+3.3V: C7.1, C8.2, J4.1, J5.1, J6.1, J7.1, J7.5, J11.1, JP1.1 (A), JP1.2 (B), R5.1, R6.1, R7.1, U1.1 (3V3), U2.1 (VCC_IN)
+5V: C3.1, C4.1, C5.1, C6.1, D1.1 (K), D2.1 (K), D3.1 (A1), D4.1 (K), U1.19 (5V), U3.9 (VCC), U3.10 (VCC)
/E22_BUSY: U1.10 (DAC_2/ADC2_CH9/GPIO26), U3.14 (BUSY)
/E22_DIO1: U1.8 (32K_XN/GPIO33/ADC1_CH5), U3.13 (DIO1)
/E22_NRST: U1.11 (ADC2_CH7/GPIO27), U3.15 (NRST)
/E22_NSS: U1.29 (GPIO5), U3.19 (NSS)
/E22_RXEN: U1.12 (MTMS/GPIO14/ADC2_CH6), U3.6 (RXEN)
/E22_SCK: U1.30 (GPIO18), U3.18 (SCK)
/E22_TXEN: U1.15 (MTCK/GPIO13/ADC2_CH4), U3.7 (TXEN)
/GPS_RX: J4.4, U1.27 (GPIO16)
/GPS_TX: J4.3, U1.28 (GPIO17)
/MISO: U1.31 (GPIO19), U3.16 (MISO)
/MOSI: U1.37 (GPIO23), U3.17 (MOSI)
/OneWire: J5.3, R5.2, U1.9 (DAC_1/ADC2_CH8/GPIO25)
/SCL: J6.3, J7.3, J11.3, R7.2, U1.36 (GPIO22), U2.3 (SCL)
/SDA: J6.4, J7.4, J11.4, R6.2, U1.33 (GPIO21), U2.4 (SDA)
GND: C1.2, C2.2, C3.2, C4.2, C5.2, C6.2, C7.2, C8.1, D3.2 (A2), D4.2 (A), D5.2 (A), H1.1, H2.1, H3.1, H4.1, J1.2, J2.4 (GND), J3.1, J4.2, J5.2, J6.2, J7.2, J8.2 (Ext), J9.2, J10.2, J12.2, NT1.2, R2.2, R3.2, R4.2, SW1.1, U1.14 (GND), U1.32 (GND), U1.38 (GND), U3.1 (GND), U3.2 (GND), U3.3 (GND), U3.4 (GND), U3.5 (GND), U3.11 (GND), U3.12 (GND), U3.20 (GND), U3.22 (GND), U4.2 (GND)
unnamed: D1.2 (A), J2.1 (V+)
unnamed: D2.2 (A), U4.1 (VO+)
unnamed: D5.1 (K), F1.2, U4.3 (IN+)
unnamed: J1.1, R1.1
unnamed: J2.2 (CC1), R4.1
unnamed: J2.3 (CC2), R3.1
unnamed: F1.1, J3.2
unnamed: J8.1 (In), R8.1
unnamed: J9.1, U3.8 (DIO2)
unnamed: J10.1, SW1.2, U1.13 (MTDI/GPIO12/ADC2_CH5)
unnamed: J11.2, JP2.1 (A), JP2.2 (B), NT1.1, U2.2 (GND)
unnamed: J12.1, U4.4 (EN)
unnamed: C1.1, R1.2, R2.1, U1.7 (32K_XP/GPIO32/ADC1_CH4)
unnamed: C2.1, U1.2 (CHIP_PU)
unnamed: R8.2, U3.21 (ANT)

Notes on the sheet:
OPTIONEN: • JP1 & JP2 dienen zum ggf. Auskreuzen der Anschlüsse · JP10 für externen Taster am Deckel • D3 <> D4 wahlweise
GND
SCL
+3.3V
GPS_TX
OneWire
SDA
GPS_RX
E22_DIO1

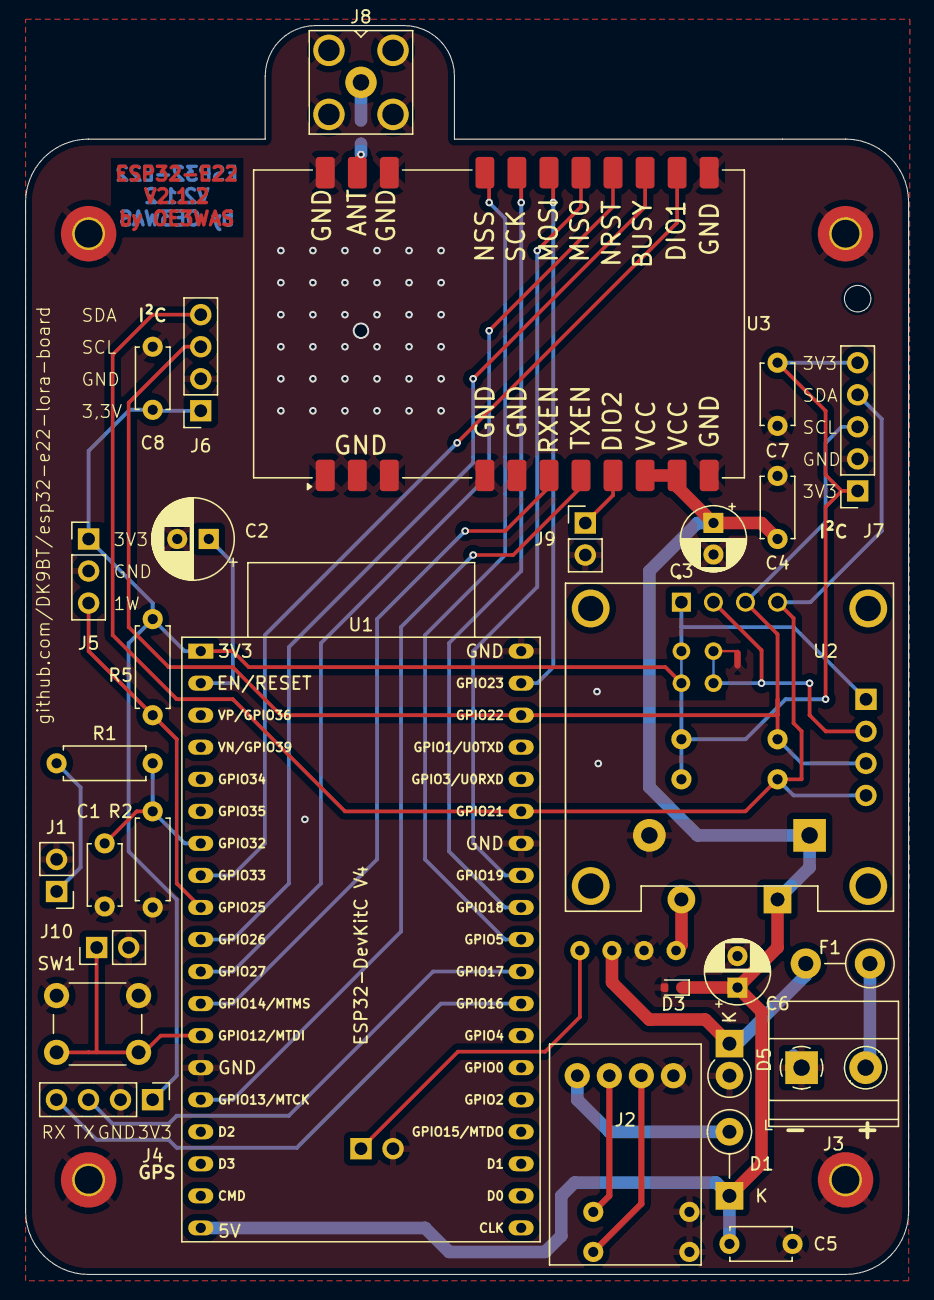
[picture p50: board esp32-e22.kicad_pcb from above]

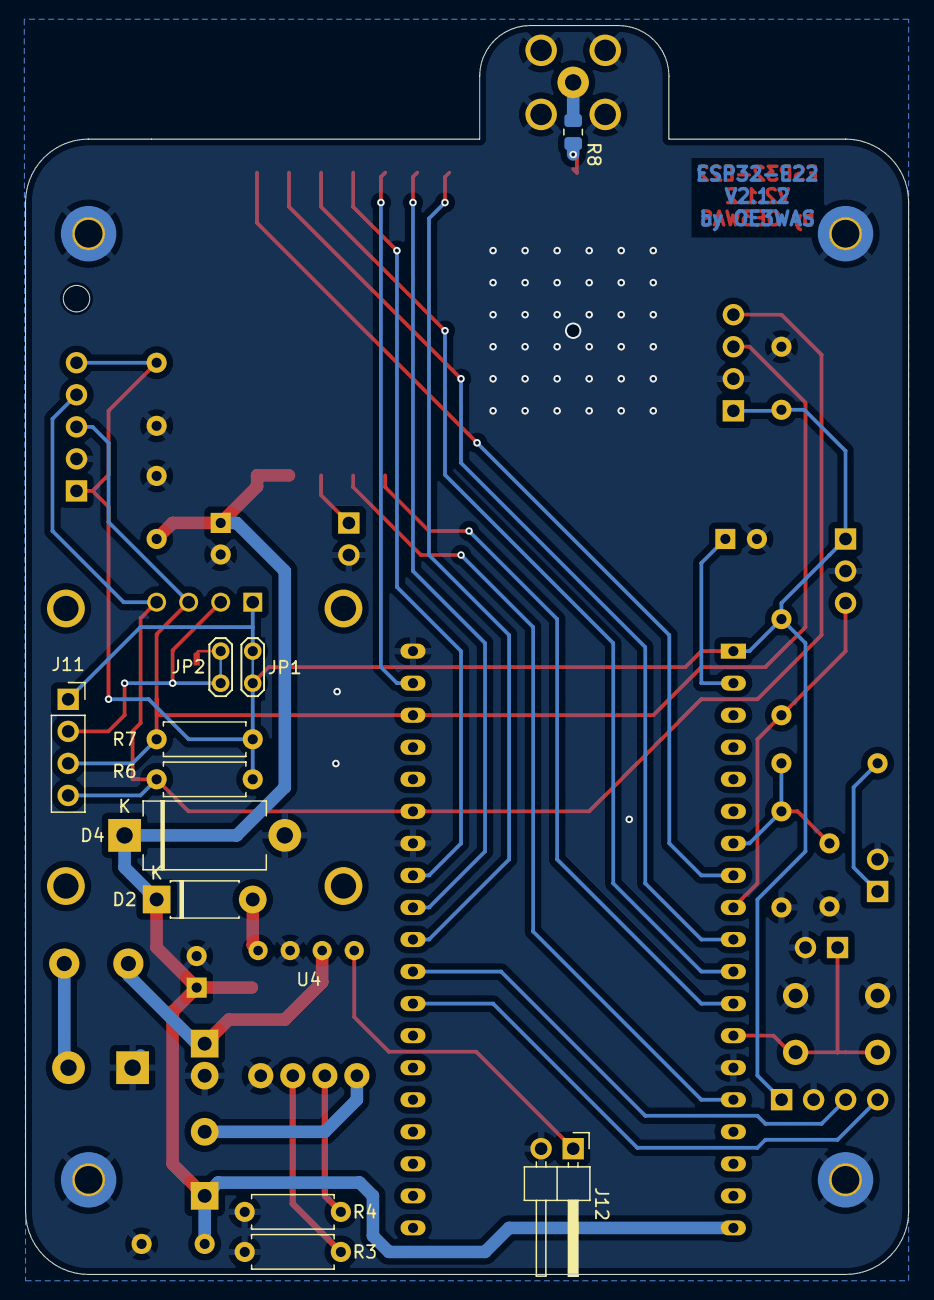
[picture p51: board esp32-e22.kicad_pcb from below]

Board: 2 copper layers, 70.0 x 99.0 mm, 46 parts (12 on the bottom side), 32 nets.

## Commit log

2024-10-03 add usb-c connector
    [esp32-e22.kicad_pcb, esp32-e22.kicad_sch]
2024-10-03 added schematic and pictures from oe5hwn board
2024-10-04 update to OE3WAS V2.0.2
    [esp32-e22.kicad_pcb, esp32-e22.kicad_sch]
2024-10-04 update to OE3WAS V2.0.3
    [esp32-e22.kicad_pcb, esp32-e22.kicad_sch]
2024-10-04 added schematic pdf of V2.0.3
2024-10-04 update to V2.0.4 (fixed ERC Fails in schematic)
    [esp32-e22.kicad_sch]
2024-10-04 fixed some missing footprints -> V2.0.5
    [esp32-e22.kicad_pcb, esp32-e22.kicad_sch]
2024-10-06 update to v2.0.6
    [esp32-e22.kicad_pcb, esp32-e22.kicad_sch]
2024-10-07 update to v2.0.7
    [DM-OLED096-636.step, E22-400M30S-3D.STEP, SMA_221789-1.step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]
2024-10-07 update to v2.0.8
    [esp32-e22.kicad_pcb, esp32-e22.kicad_sch]
2024-10-07 update footprint of sma connector
    [esp32-e22.kicad_pcb]
2024-10-08 update to v2.0.9
    [esp32-e22.kicad_pcb, esp32-e22.kicad_sch]
2024-10-09 move to folder ESP32-E22_V2.1.x
    [DM-OLED096-636.step, E22-400M30S-3D.STEP, SMA_221789-1.step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]
2024-10-09 move to KiCad subfolder
    [DM-OLED096-636.step, E22-400M30S-3D.STEP, SMA_221789-1.step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]
2024-10-09 rename folder
    [DM-OLED096-636.step, E22-400M30S-3D.STEP, SMA_221789-1.step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]
2024-10-09 new Version 2.0.10 & 2.0.6
    [USB-C_vert_breakout.STEP, esp32-e22.kicad_pcb, esp32-e22.kicad_sch]
2024-10-11 real update
    [USB-C_vert_breakout.STEP, esp32-e22.kicad_pcb, esp32-e22.kicad_sch]
2024-10-11 Flood filled GND Back and Front
    [esp32-e22.kicad_pcb]
2024-10-11 some footprint changes
    [esp32-e22.kicad_pcb, esp32-e22.kicad_sch]
2024-10-11 corrected footprints symbols and 3d Models for our custom parts
    [esp32-e22.kicad_pcb, esp32-e22.kicad_sch]
2024-10-11 some fixes
    [esp32-e22.kicad_pcb, esp32-e22.kicad_sch]
2024-10-11 Beta V2.1.0
    [esp32-e22.kicad_pcb]
2024-10-11 small fix
    [esp32-e22.kicad_pcb]
2024-10-11 version update SCH
    [esp32-e22.kicad_sch]
2024-10-13 stückliste
    [esp32-e22.csv]
2024-10-13 update BOM
    [esp32-e22_V2.1.0_BOM.xls]
2024-10-17 new V 2.1.1
    [DM-OLED096-636.step, E22-400M30S-3D.STEP, SMA_221789-1.step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]
2024-10-20 update to V2.1.1-α2
    [esp32-e22.kicad_pcb, esp32-e22.kicad_sch]
2024-10-24 mask update
    [esp32-e22.kicad_pcb]
2024-10-24 PCB V2.1.1-α3
    [esp32-e22.kicad_pcb]
2024-10-25 SCH & PCB α5
    [HW-613.step, esp32-e22.kicad_pcb, esp32-e22.kicad_sch]
2024-10-25 update SCH
    [esp32-e22.kicad_sch]
2024-10-30 update PCB
    [esp32-e22.kicad_pcb]
2024-11-02 update PCB V2.1.1 BETA
    [esp32-e22.kicad_pcb]
2024-11-03 update Doku
    [esp32-e22.kicad_pcb]
2024-11-05 new Version 2.1.2
    [DM-OLED096-636.step, E22-400M30S-3D.STEP, HW-613.step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]
2024-11-05 update Assembly
    [SMA-angled.STEP, esp32-e22.kicad_pcb, esp32-e22.kicad_sch]
2024-11-14 add assembly
2024-11-17 PCB β3
    [esp32-e22.kicad_pcb, esp32-e22.kicad_sch]
2024-11-22 add jlcpb gerber production files
    [BOM-esp32-e22.csv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]
2025-02-04 archive old
    [DM-OLED096-636.step, E22-400M30S-3D.STEP, SMA_221789-1.step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]
2025-11-24 Revise README with new copyright and module details
    Updated copyright date and added additional information about the INA226 module and BME280 sensor.
